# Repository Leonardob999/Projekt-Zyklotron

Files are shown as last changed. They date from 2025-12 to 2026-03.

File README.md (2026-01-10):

# Projekt-Zyklotron

Das ist unser Versuch eine eine Modell des im Cern betrienen Zyklotrons zu bauen. Unsere Nachbildung nutzt magnetische Felder um eine Magnetkugel anzutreiben. In diesem Github ist alles was ihr braucht um es zu benutzen und auch nachzubauen.

## Unser [Github](https://github.com/Leonardob999/Projekt-Zyklotron)

## Aufbau
12V an den vorgesehenen Anschlüssen anschließen. 

## Benutzung

Durch drehen des Drehknopfs kann man die Seite die auf den Display angezeigt wird auswählen. Durch drücken des Knopfes wird die Seite bestätigt und man kann jetzt den aktuellen Wert verändern. Durch erneutes betätigen des Knopfes kommt man wieder in die Seitenauswahl zurück.

## Bilder

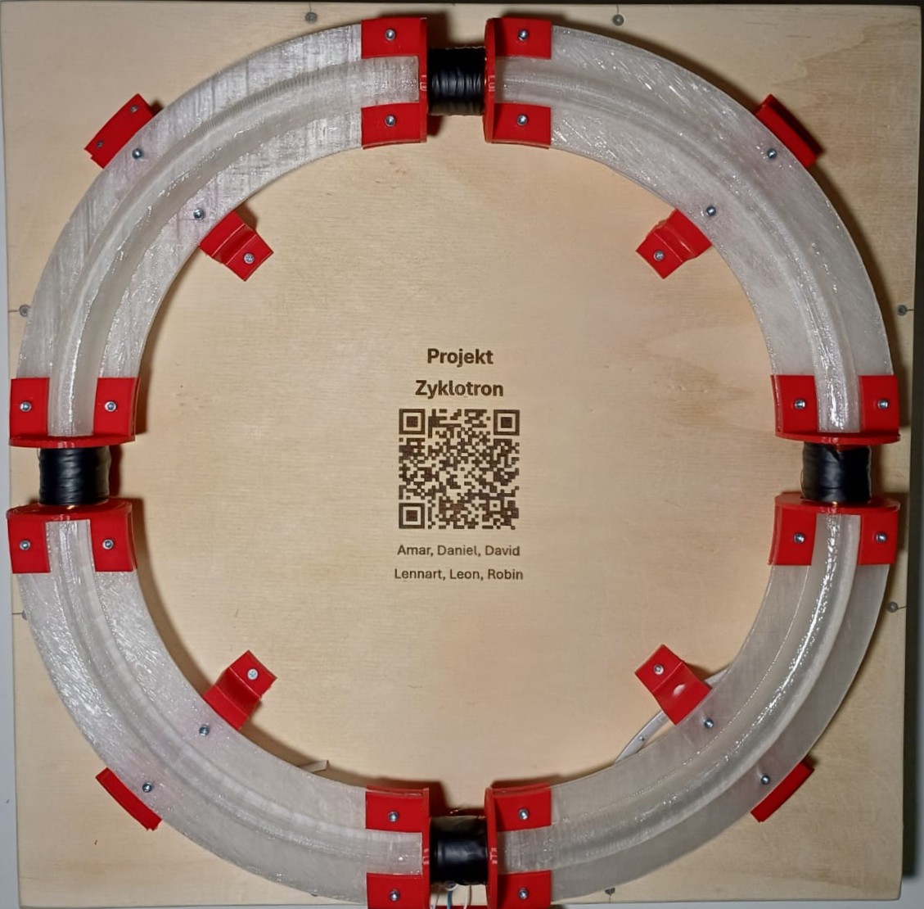
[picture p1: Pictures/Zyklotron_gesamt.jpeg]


## Autoren

- [@FritzWilli1](https://www.github.com/FritzWilli1)
- [@Fl4SH3Z](https://www.github.com/Fl4SH3Z)
- [@Danieldev1804](https://www.github.com/Danieldev1804)
- [@Leonardob999](https://www.github.com/Leonardob999)
- @Amar
- @David

## Quellen
Unsere Zyklotron Nachbildung wurde inspiriert durch ein Video von [@Marcin Poblocki](https://www.youtube.com/watch?v=sm_-i4a_vSU)

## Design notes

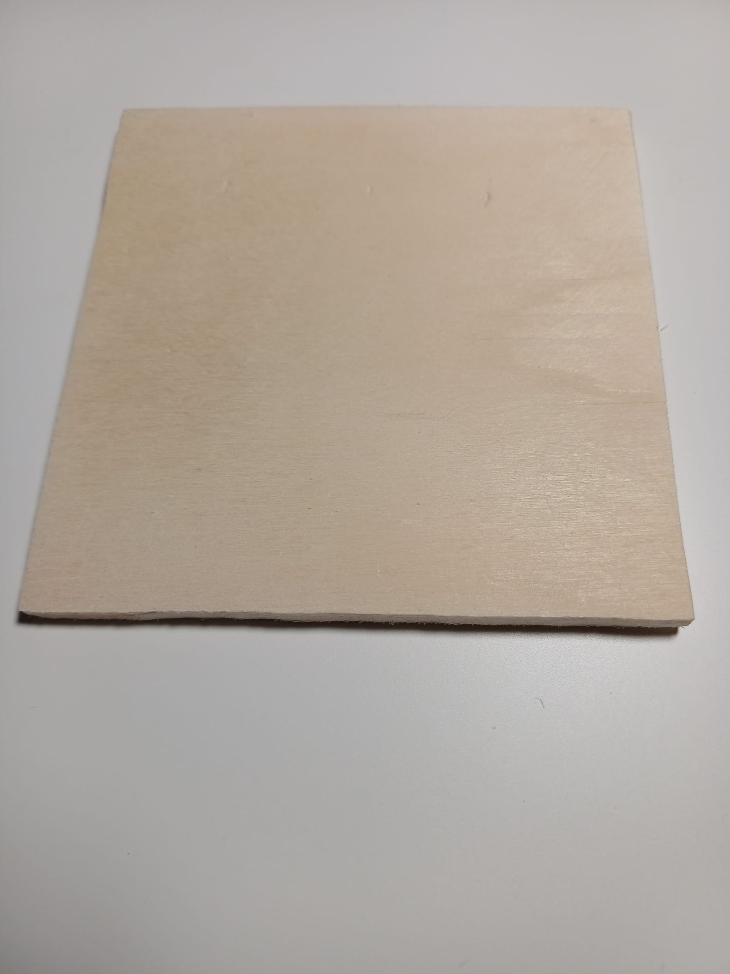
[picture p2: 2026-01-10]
Pictures/Brett.jpeg

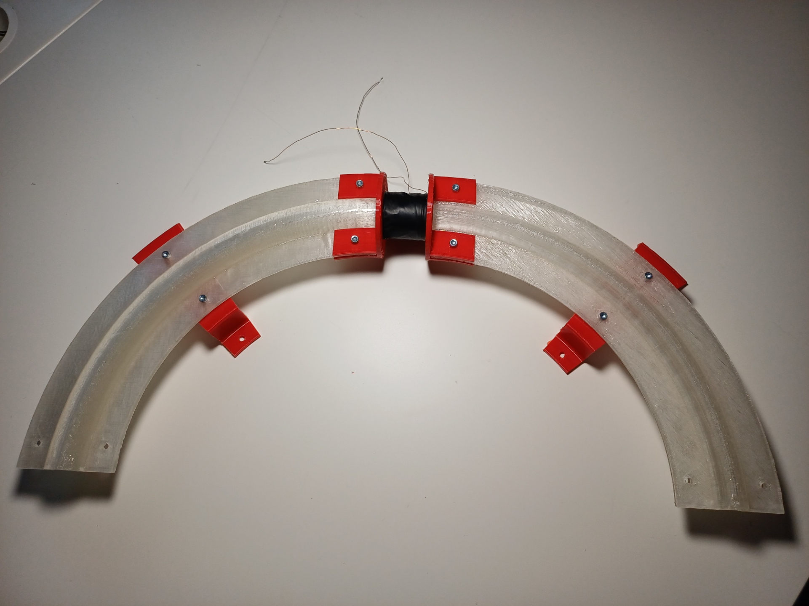
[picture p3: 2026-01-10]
Pictures/Halbr.jpg

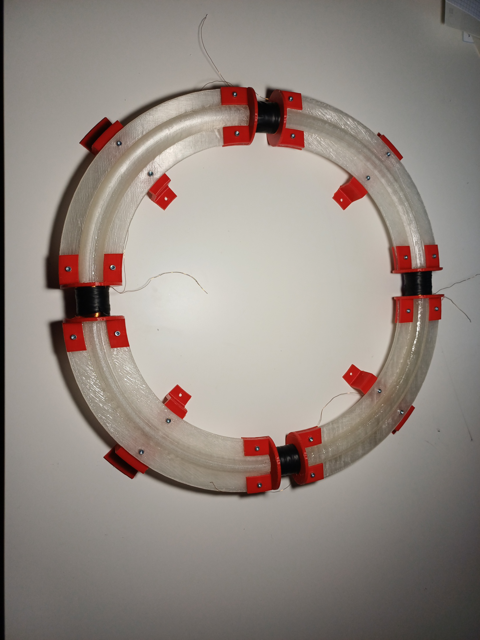
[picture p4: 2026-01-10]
Pictures/Ganzo.jpg

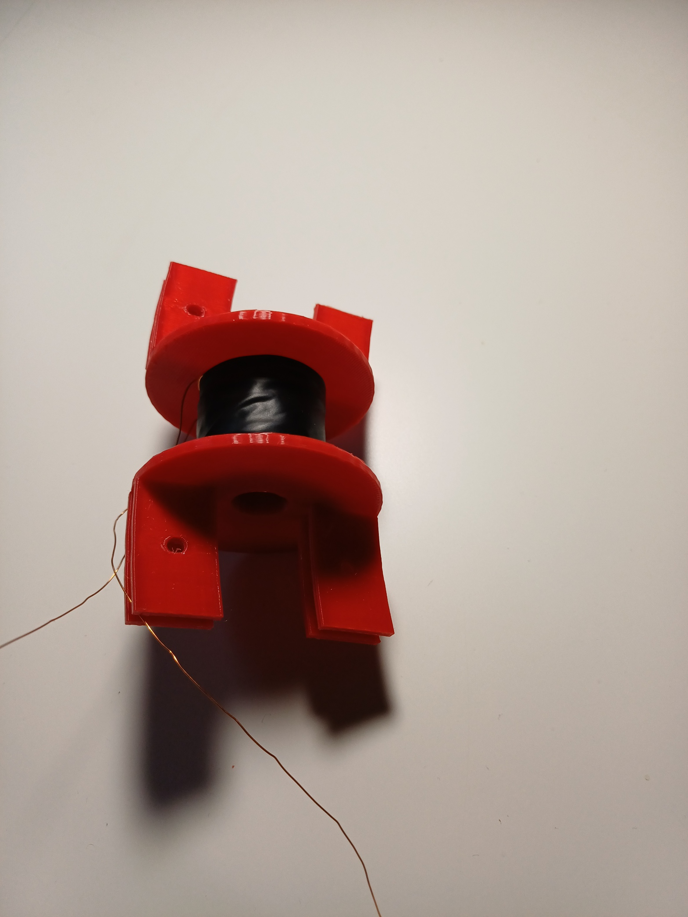
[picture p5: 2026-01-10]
Pictures/Spule.jpg

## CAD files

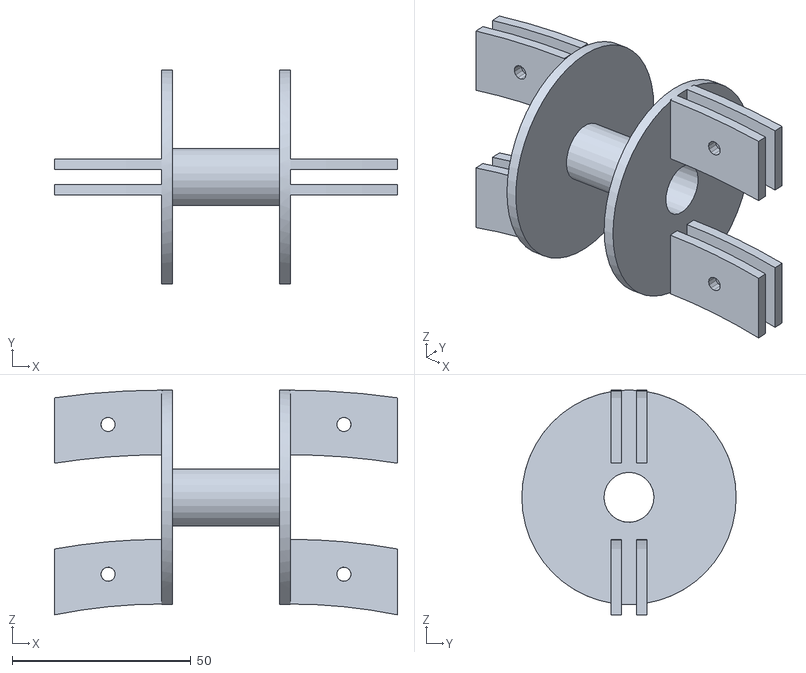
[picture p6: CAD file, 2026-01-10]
CAD/Models/stl/Verbindungsstück.stl
96.0 x 60.0 x 62.9

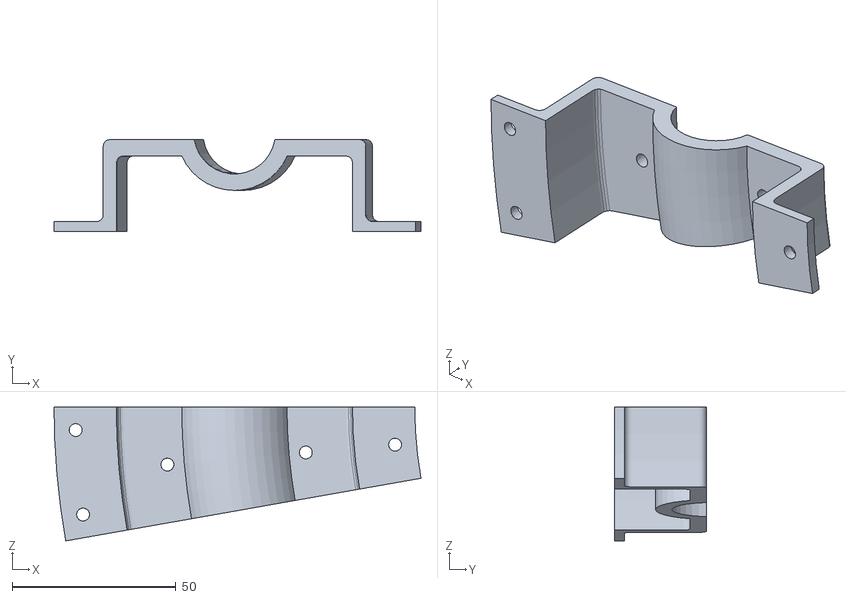
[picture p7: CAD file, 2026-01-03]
CAD/Models/stl/Stütze-Mk3.stl
111.9 x 28.0 x 40.8

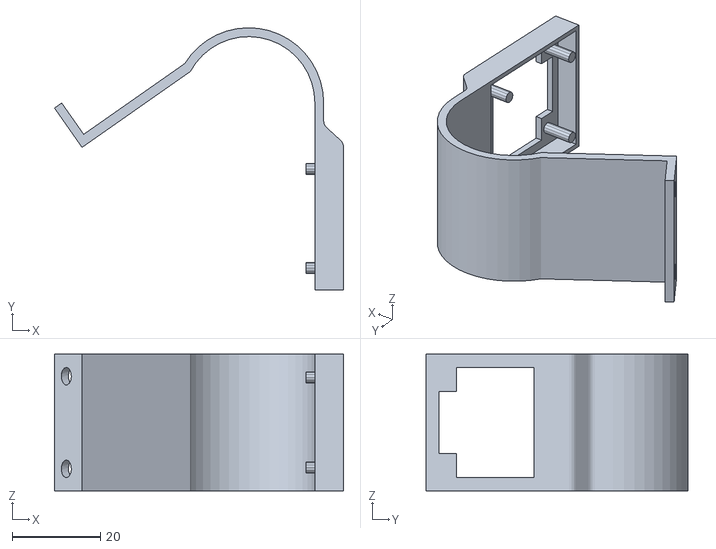
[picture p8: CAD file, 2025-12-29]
CAD/Models/stl/Bildschirmhalter-Mk5.stl
65.5 x 59.5 x 31.0

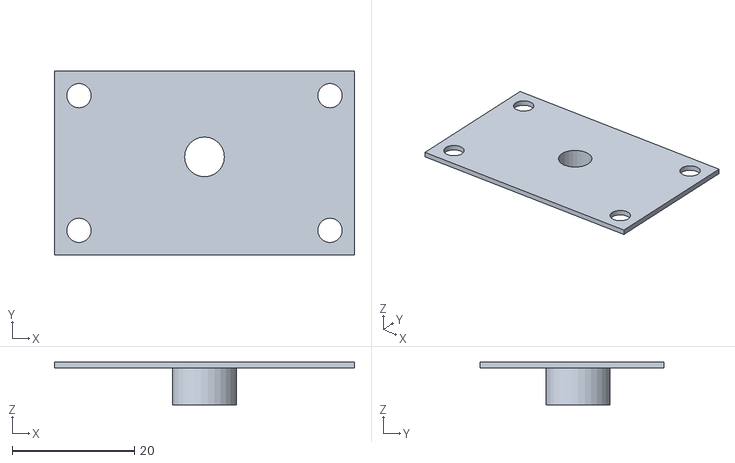
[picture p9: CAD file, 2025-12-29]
CAD/Models/stl/RE-Halter.stl
49.0 x 30.0 x 7.00

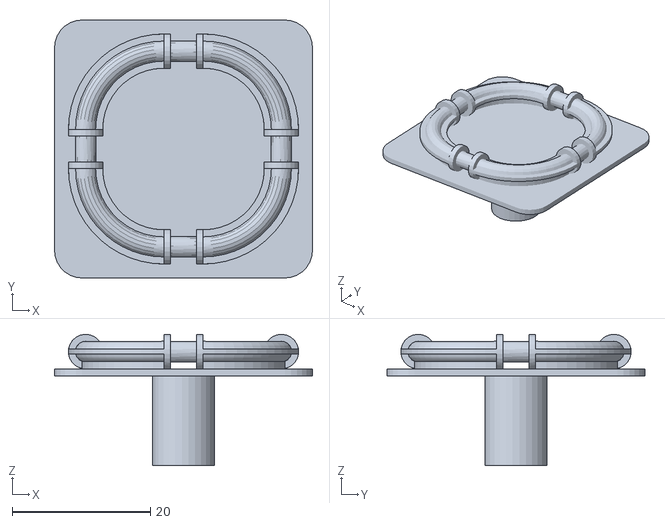
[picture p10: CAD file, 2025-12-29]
CAD/Models/stl/Knopf-Mk2.stl
37.3 x 37.3 x 19.0

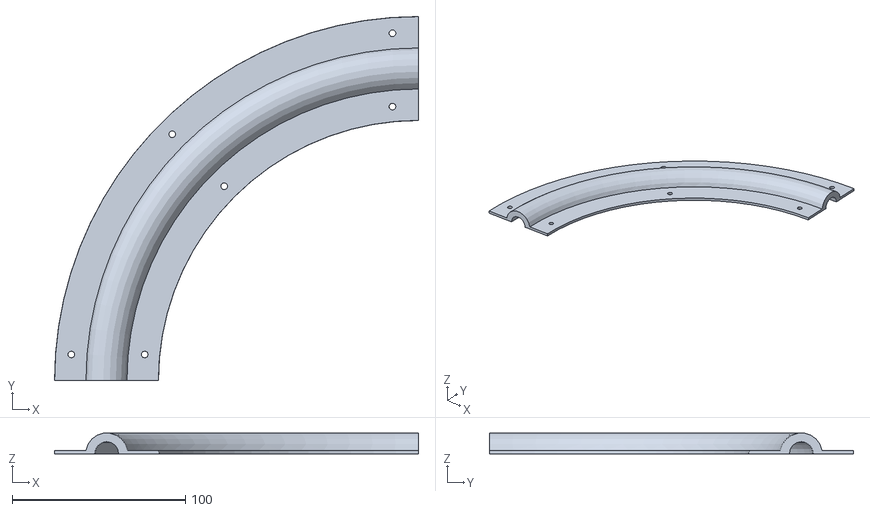
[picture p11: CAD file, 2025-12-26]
CAD/Models/stl/Kurventeil-dick.stl
210.0 x 210.0 x 11.9

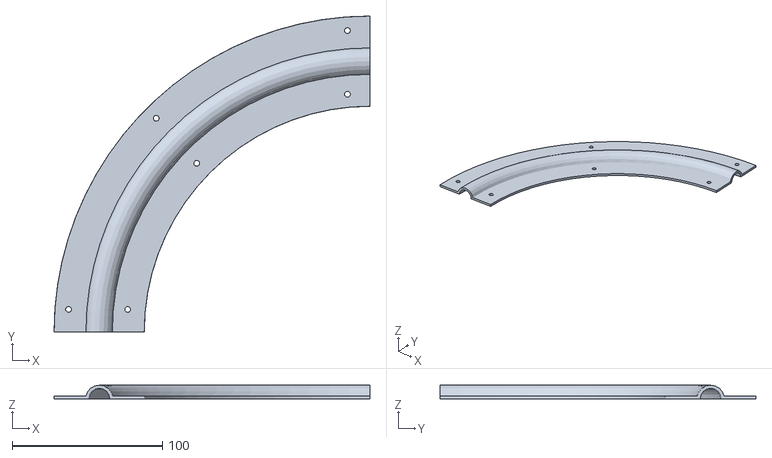
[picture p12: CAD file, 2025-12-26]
CAD/Models/stl/Kurventeil-dünn.stl
210.0 x 210.0 x 9.00

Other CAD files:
CAD/Models/ipt/Bildschirmhalter-Mk5.ipt
CAD/Models/ipt/Knopf-Mk2.ipt
CAD/Models/ipt/Kurventeil-dick.ipt
CAD/Models/ipt/Kurventeil-dünn.ipt
CAD/Models/ipt/RE-Halter.ipt
CAD/Models/ipt/Stütze-Mk3.ipt
CAD/Models/ipt/Verbindungsstück.ipt

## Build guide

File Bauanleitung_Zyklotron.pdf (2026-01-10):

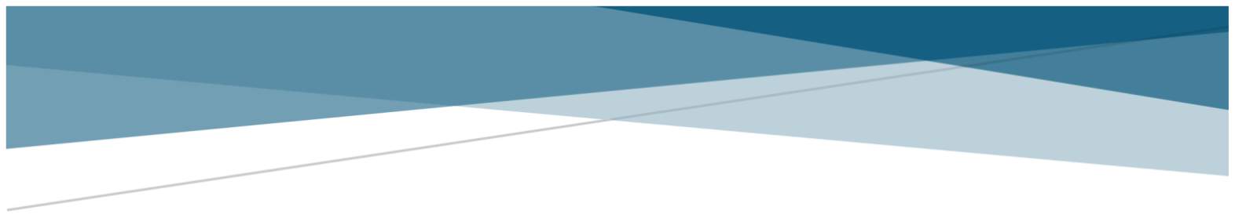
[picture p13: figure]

# ZYKLOTRON-BAUANLEITUNG

## Amar, Daniel, David, Lennart, Leon, Robin

https://leonardob999.github.io/Projekt-Zyklotron/

Amar, Daniel, David | Zyklotron
Lennart, Leon, Robin | 10. Jan. 2025

### 1 INHALT

### 2 MATERIALLISTE UND BENÖTIGTE WERKZEUGE

Mechanische Komponenten:
- 2x1KG Spulen PVB (transparent)
- PLA/PETG Spule Farbe egal
- 24x M3*16mm Zylinderkopfgewindeschrauben
- 12xM3*16mm Senkkopfgewindeschrauben
- 16xM3*25mm Senkkopfholzschrauben
- 36x M3 Muttern
- Isopropanol
- Neodymmagnetkugel
- 500mmx500mmx5mm Holzbrett
- 4x Holzlatten
Elektrische Komponenten:
- 4x 87m*0,35mm Kupferlackdraht
- Kabel
- 1xLED-Band 3-farbig (alle 15cm aufteilbar)
- Widerstände: 4x1,2kΩ; 4x4,7kΩ; 4x20kΩ; 4x10kΩ
- 2xLaborkabelbuchsen
- 1xEsp32 Microcontroller
- 1xRotary Encoder
- 1xOLed Display
- 4xHall Sensoren A3144
- 1xSpannungsregler L7805CV
- 4xFet mit Freilaufdiode
- 4xTransistor
Werkzeuge:
- Pinsel
- Dremel/Feilen
- Zange/Seitenschneider
- Lötkolben
- 3D-Drucker
- Akkuschrauber
- Stichsäge

### 3 EINFÜHRUNG

Teilchenbeschleuniger sind heutzutage wichtige Werkzeuge in Forschungsgebieten wie Materien- und Materialforschung, aber auch in der Medizin oder der Energietechnik kommen sie zum Einsatz. Da diese jedoch groß und technisch hochkomplex sind, werden solche physikalischen Abläufe vereinfacht und in Modellen dargestellt. Dies ist genau das Ziel dieses Projektes. Durch den Bau dieses Zyklotrons, als Modell eines Teilchenbeschleunigers, sind die physikalischen Zusammenhänge einfacher zu verstehen. Außerdem wird durch das Zyklotron ermöglicht theoretische Inhalte in die Praxis umzusetzen.
Dieses Projekt weicht an einigen Stellen vom realen Teilchenbeschleuniger ab, zum Beispiel basiert es nicht auf dem zusammenwirken von elektrischen und magnetischen Feldern, sondern nur auf dem Einsatz magnetischer Felder durch elektrisch gesteuerte Spulen. Daher stellt dieses Projekt nicht die genaue Wirkweise eines Teilchenbeschleunigers nach, kann aber dennoch physikalische Zusammenhänge, wie Induktion und Magnetfelder, verständlich darstellen.

### 4 VORBEREITUNG 3D-DRUCKTEILE

4.1 3D-DRUCK
Als ersten Schritt des Baus ist es nötig, die verschiedenen Modelle mit einem 3D-Drucker auszudrucken. Es werden benötigt (siehe GitHub):
- 6x Kurventeil-dick (transparentes Material)
- 2x Kurventeil-dünn (transparentes Material)
- 4x Verbindungsstück (beliebiges Material)
- 4x Stütze-Mk3 (beliebiges Material)
- 1x Bildschirmhalter-Mk5 (beliebiges Material)
- 1x Knopf-Mk2 (beliebiges Material)
- 1x RE-Halter (beliebiges Material)
Es ist auch möglich 8x Kurventeil-dünn zu verwenden. In folgender Anleitung wird jedoch 6x Kurventeil-dick verwendet, da in der vorrausgegangenen Konstruktion zuerst zu hohe Sicherheiten mit eingebaut wurden. Als dies auffiel, war der Großteil der Kurven allerdings schon gedruckt.
Die Druckeinstellungen müssen je nach Drucker und Material individuell eingestellt werden. Bei dem transparenten PVB ist es jedoch wichtig darauf zu achten, dass für eine optimale Transparenz des Filaments der Infill des Drucks auf 100% zu stellen ist, da kleine Druckfehler und Lufteinschlüsse die Transparenz deutlich beeinträchtigen. Als Füllmuster wird das geradlinige Füllmuster verwendet. Zudem sollten alle Oberflächen von den Teilen gebügelt werden, um eine saubere Oberfläche zu ermöglichen, wobei die Flussrate 20% beträgt. Schürze und Rand (Skirt und Brim) können deaktiviert werden. Stützmaterial muss generiert werden, wobei die Form irrelevant ist. Für weitere Details kann das Druckprofil via GitHub heruntergeladen werden. Dieses ist im CAD-Ordner als config.ini zu finden, muss allerdings noch auf den verwendeten Drucker angepasst werden.
Die Stützen, die Verbindungsstücke, die Displayhalterung und die Teile für den Rotary Encoder können aus einem beliebigen stabilen und plastischen Stoff gedruckt werden, da hier die Transparenz keine Rolle spielt. Hierbei werden die Teile mit der jeweiligen Standardeinstellung des Materials gedruckt.

### 4.2 NACHBEARBEITUNG

Nachdem die Teile vom 3D-Drucker fertiggestellt wurden, wird der Großteil des Supports mithilfe von Zangen und Seitenschneidern entfernt. Danach müssen die feineren, noch übrig gebliebenen, Strukturen des Supports mithilfe eines Dremels oder einer Feile entfernt werden (Schritt 1). Besonders zu beachten ist hier, dass an Verbindungsrelevanten Stellen nicht zu viel Material abgetragen werden darf, damit die Schraubverbindungen einwandfrei funktionieren.
Nachdem der Support so gut wie möglich entfernt wurde, sollten die Kurventeile noch mit Isopropanol behandelt werden, um die Transparenz und die Materialoberfläche zu verbessern. Hierfür wird ein Pinsel in das Isopropanol getunkt und dieses vorsichtig auf den Druck aufgetragen. Dieser Vorgang wird mehrfach wiederholt, bis die Oberfläche möglichst glatt und widerstandslos für die Kugel ist und das Kurventeil möglichst durchsichtig.

### 5 ZUSAMMENBAU 3D-DRUCK

Nachdem alle 3D-Druckteile fertig nachbearbeitet wurden, müssen die Spulen auf die Verbindungsstücke gewickelt werden (Schritt 2). Hierfür kann ein Akkuschrauber verwendet werden. Jede Spule wird einzeln mit 87m Draht gewickelt. Es muss darauf geachtet werden, dass an beiden Enden noch genug freier Draht ist, um die Spule an die Schaltung anschließen zu können. Es sollte außerdem darauf geachtet werden, dass die Spulen möglichst genau gewickelt werden, da eine unsauber gewickelte Spule das Magnetfeld negativ beeinflusst. Wenn die Spule gewickelt wurde wird sie mit Isoband umwickelt um den Draht zu fixieren.
Für den Zusammenbau werden M3 Schrauben und Muttern verwendet.
Hilfreich ist es, wenn zuerst zwei Kurventeile übereinandergelegt und mit einer Stütze an den mittleren Löchern verbunden werden (Schritt 3). Dies wird für alle vier Viertel gemacht, wobei die zwei Kurventeile-dünn optimalerweise auf der Oberseite und diagonal gegenüber platziert werden sollten. Daraufhin müssen die Viertel nun mit den Verbindungsstücken verbunden werden, indem diese auf die vier Viertel geschoben und daraufhin mit Schrauben verbunden werden. (Schritt 4 + 5)

### 6 BASIS

### 6.1 BRETT

Wenn das Zyklotron zusammengesetzt wurde kann dieses nun mittig auf das Brett gesetzt werden. Danach werden mithilfe eines Bleistiftes die Löcher in den Stützen markiert. Außerdem werden die Löcher für die Kabel markiert. Diese müssen pro Verbindungsstück zentral unter der Spule sitzen sowie rechts und links von der Spule mit einem Abstand von ca. 32mm zum zentralen Loch. Die markierten Löcher können nun gebohrt werden (Schritt 6). Zudem wird der Platz in der Mitte ausgemessen, um die Gravur zu zentrieren. Danach wird jetzt die Beschriftung in der Mitte des Brettes eingraviert (Schritt 7). Nachdem die Gravur fertiggestellt wurde, sollte das Brett möglichst mit Druckluft abgeblasen werden, um es von liegengebliebenen Spänen zu befreien. Danach kann das Brett noch eingewachst werden, um es vor Verschmutzung oder Beschädigungen zu schützen (WICHTIG: Das Wachs erst nach der Gravur auftragen! Akute Brandgefahr!).

### 6.2 RAHMEN

Bevor mit dem Bau des Rahmens begonnen werden kann, muss zuerst die Frontlatte bearbeitet werden, das heißt in die Frontlatte muss eine Aussparung für den Rotary Encoder gesägt werden (Schritt 8). Danach wird der Rahmen, der dem Brett Stabilität verleiht und die Schaltung versteckt aus 4 Latten und 8 Holzschrauben zusammengebaut. Dabei muss darauf geachtet werden, dass dieser mit dem Brett abschließend gebaut wird. Außerdem müssen an beliebiger Stelle noch zwei passende Langlöcher für den Stromanschluss gebohrt werden. Dieser wird mithilfe zweier Laborkabelbuchsen realisiert. Die Verbindung mit dem Brett wird mit 2 Schrauben pro Latte realisiert (Schritt 9). Nun wird das Zyklotron mit den vorbereiteten Löchern auf dem Brett verschraubt (Schritt 10).

### 7 SCHALTUNG

Im Folgenden muss nun noch die Schaltung, nach gezeigtem Schaltplan gelötet werden. Die Schaltung wird mithilfe einer Platine geordnet und unter das Brett geklebt. Die beiden oberen Anschlüsse GND und +12V werden mit den Laborkabelbuchsen verlötet. Beim Löten der Schaltung muss darauf geachtet werden, dass die Kabel für die Spulen, die LED-Streifen, den Rotary Encoder, und den Bildschirm lang genug sind, um durch die jeweiligen Löcher zu reichen. Außerdem muss auf die richtige Anschlussweise der verschiedenen Bauteile geachtet werden, da ansonsten die Wirkweise verändert wird, oder Teile der Schaltung beschädigt werden können.

Die Spulen werden mithilfe der zentralen Löcher unter jeder Spule an die Schaltung angeschlossen. Außerdem werden die LED-Bänder an die Innenseiten der Kurventeile befestigt, um das Zyklotron von unten zu beleuchten und damit die Kugel besser sichtbar zu machen. Hierfür werden die Löcher links und rechts der jeweiligen Spule als Kabeldurchführung verwendet. Die vier Operationsverstärker am unteren Ende stellen die vier Hall-Sensoren dar. Das Bauteil OLED ist der Bildschirm und wird mithilfe des Bildschirmhalters an der vorderen Spule befestigt. Das Bauteil RE ist der Rotary Encoder und wird nach dem Löten mit der Halterung in die Aussparung des Rahmens eingesetzt. Später wird der Bildschirm mithilfe des Rotary Encoders angesteuert, indem durch Rotation zwischen Menüs umgeschaltet wird und durch drücken ein Menü aus- oder abgewählt wird. Das drehen innerhalb eines Menüs führt zur Änderung des ausgewählten Parameters.

### 8 PROGRAMMCODE

Abschließend muss der ESP32 Microcontroller noch programmiert werden. Der dafür verwendete Code kann über GitHub heruntergeladen werden. Dieser ist unter Code/zyklotron-main zu finden. Dann wird der Ordner in der Arduino IDE geöffnet und das main.ino File auf den ESP32 geflasht. Hierbei muss insbesondere darauf geachtet werden, dass die Pins die in der Schaltung verlötet wurden mit denen im Programmcode übereinstimmen.

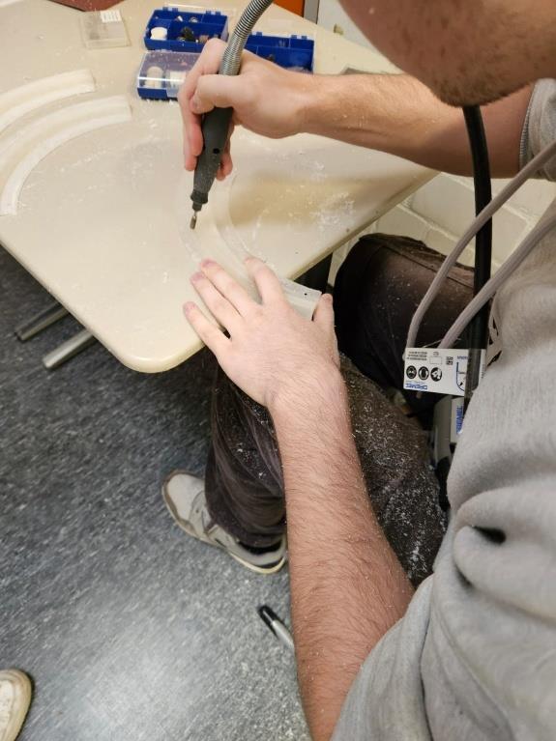
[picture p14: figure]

Abbildung 1: Nachbearbeitung

### 9 BILDANLEITUNG

SCHRITT 1:

Abbildung 5: Spule

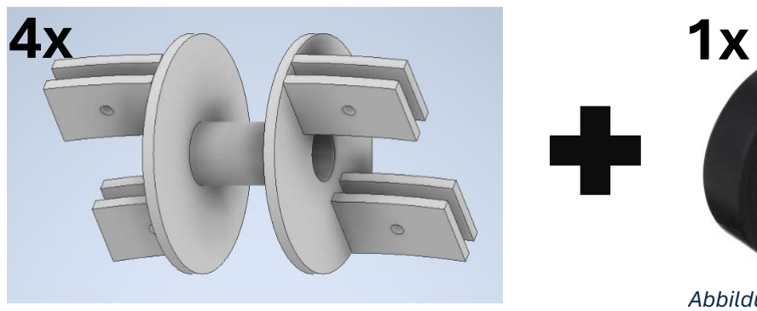
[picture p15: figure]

Abbildung 5: Verbindungsstück Modell

Abbildung 5: Isoband

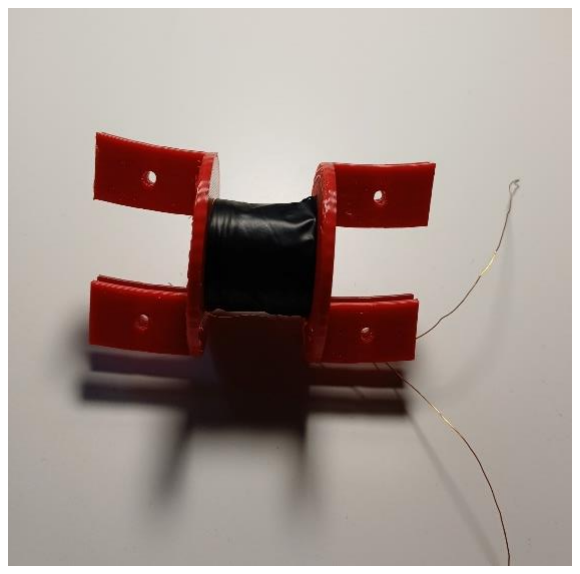
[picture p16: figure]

Abbildung 5: Verbindungsstück mit Spule

SCHRITT 2:

4x

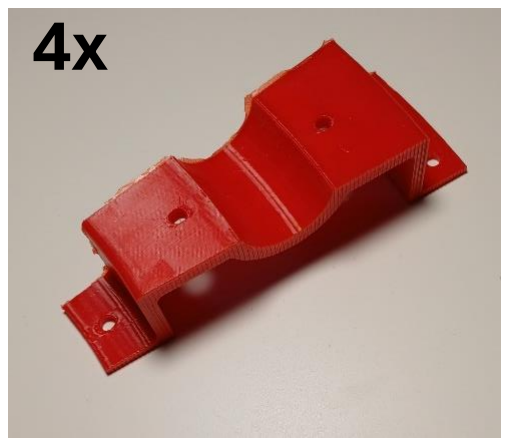
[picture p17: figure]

Abbildung 6: Stütze

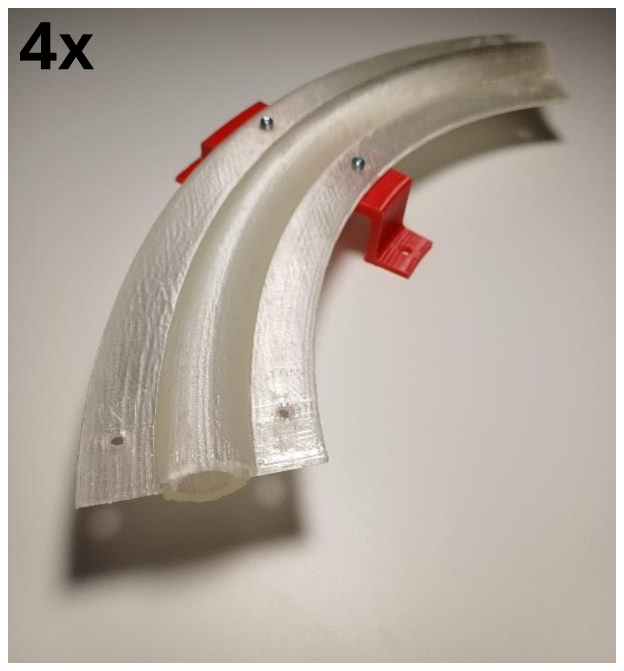
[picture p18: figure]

Abbildung 9: Viertel montiert

SCHRITT 3:

8x

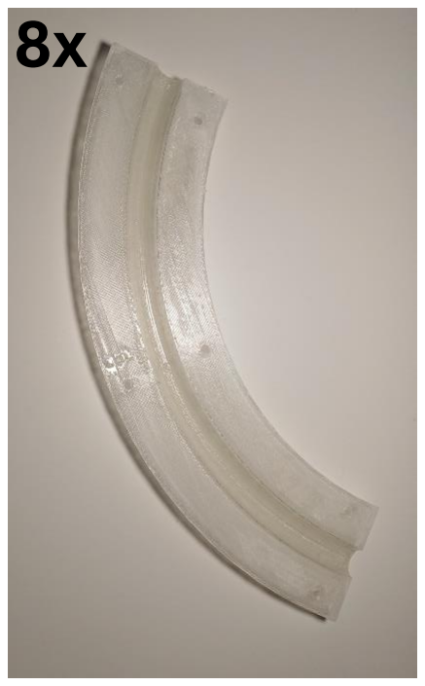
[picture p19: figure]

Abbildung 7: Kurventeil

Abbildung 8:
Schraube M3 x 16
und Mutter M3

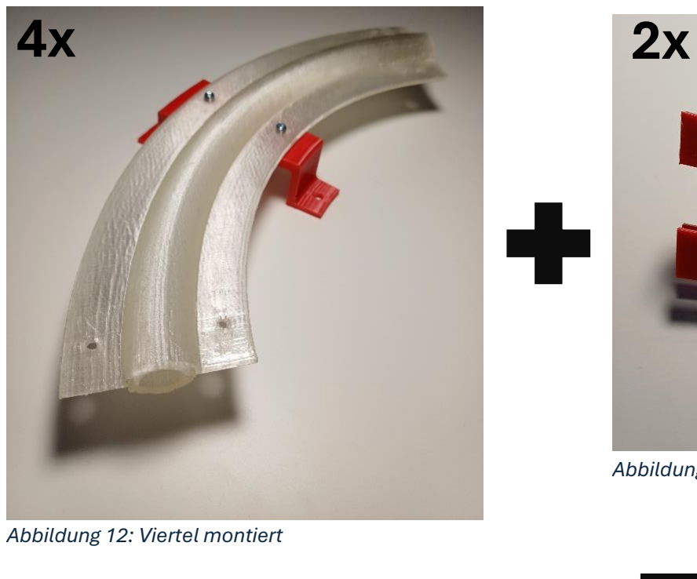
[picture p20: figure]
Abbildung 12: Viertel montiert
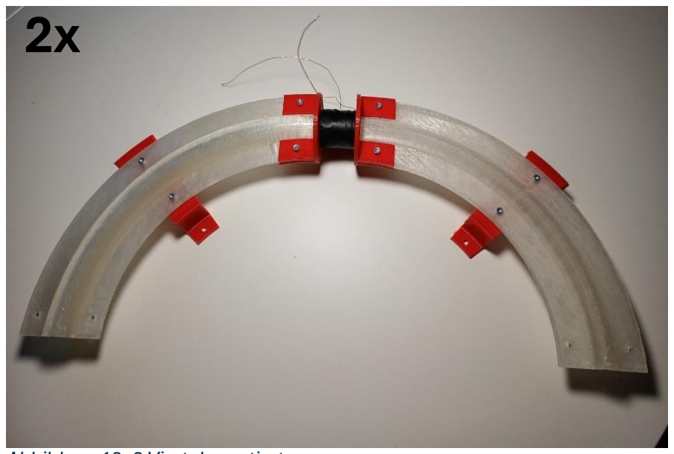
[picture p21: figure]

Abbildung 13: 2 Viertel montiert

Abbildung 12: Verbindungsstück mit Spule

SCHRITT 4:

Abbildung 15: 2 Viertel montiert

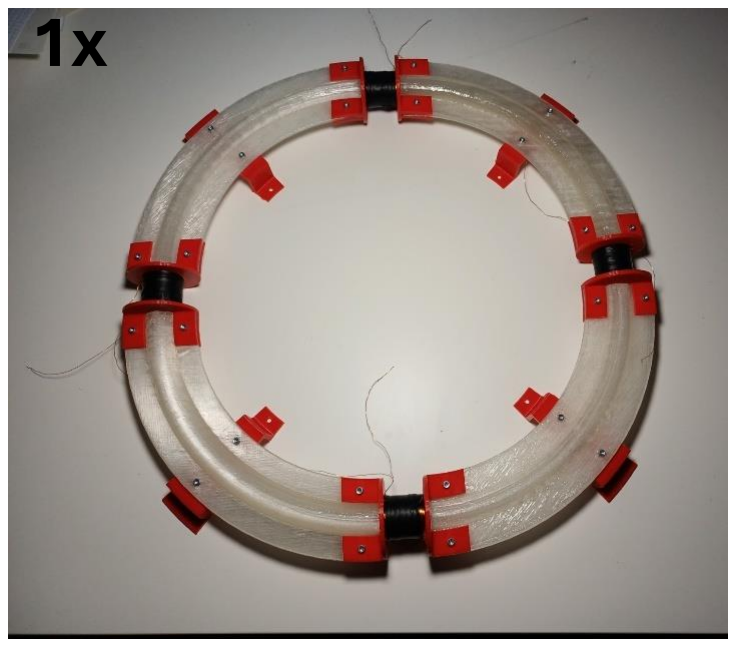
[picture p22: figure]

Abbildung 17: 4 Viertel montiert

SCHRITT 5:

Abbildung 16: Verbindungsstück mit Spule

Abbildung 14:
Schraube M3 x 16
und Mutter M3

8x

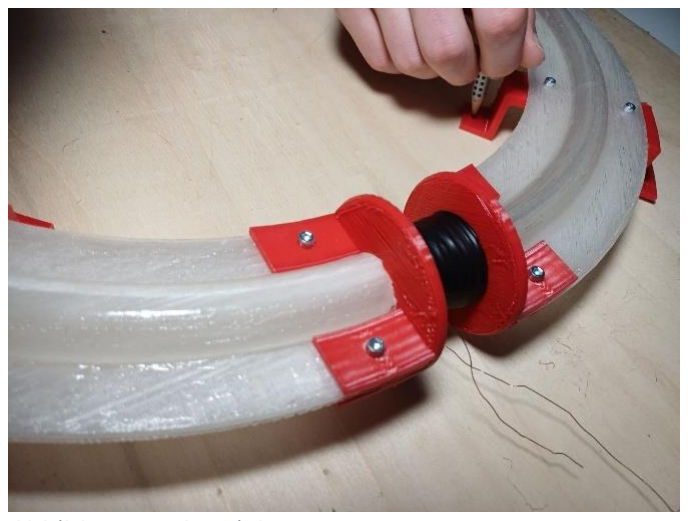
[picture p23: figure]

Abbildung 21: Anzeichnen

Abbildung 22: Bohren

SCHRITT 6:

Abbildung 20: 4 Viertel montiert

Abbildung 19: Brett 500x500 | Abbildung 18: Akkubohrmaschine

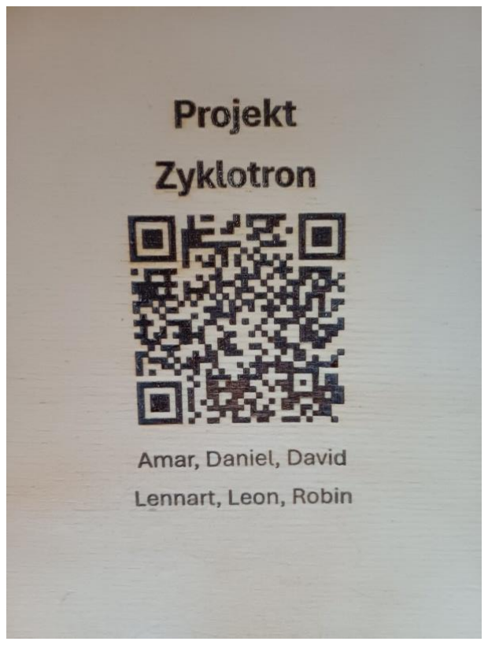
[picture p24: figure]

Abbildung 25: Gravur

SCHRITT 7:

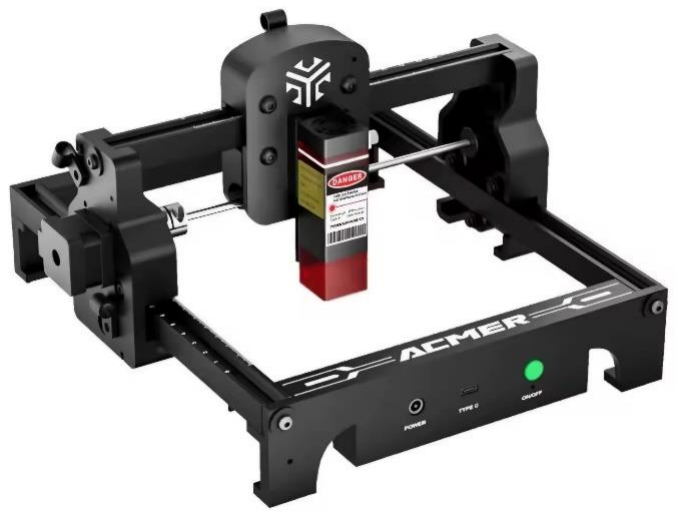
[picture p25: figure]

Abbildung 24: Brett 500x500 | Abbildung 23: Gravierer

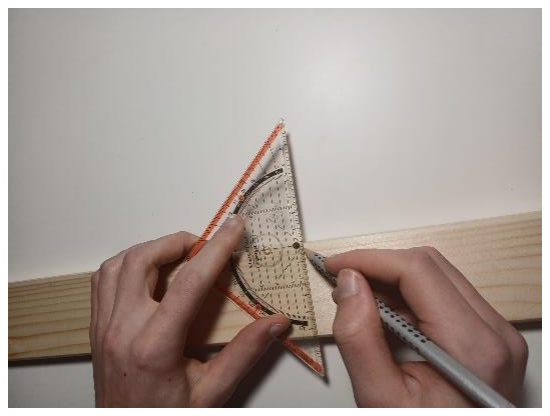
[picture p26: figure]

Abbildung 28: Latte Anzeichnen

Abbildung 29: Latte sägen

SCHRITT 8:

Abbildung 26: Latte

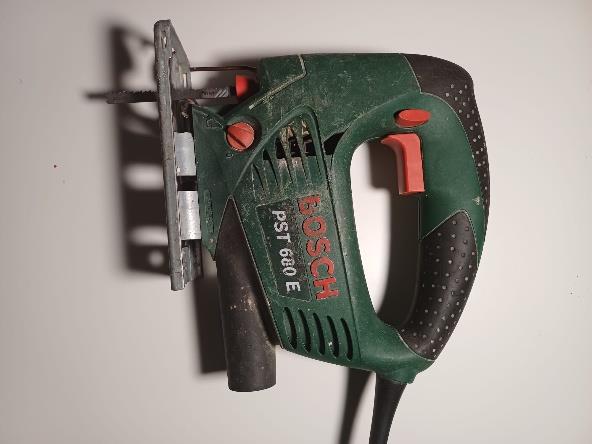
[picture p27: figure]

Abbildung 27: Stichsäge

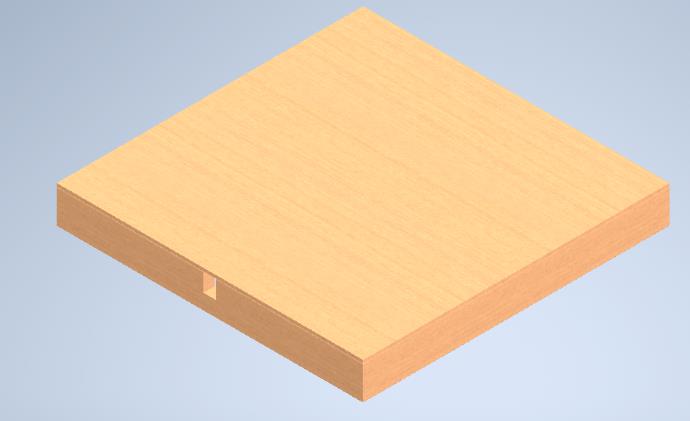
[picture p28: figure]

Abbildung 33: Brett auf Rahmen montiert

Abbildung 31: M3 x
25mm
Senkkopfschraube

SCHRITT 9:

Abbildung 30: Rahmenmodell Abbildung 32: Brett 500x500

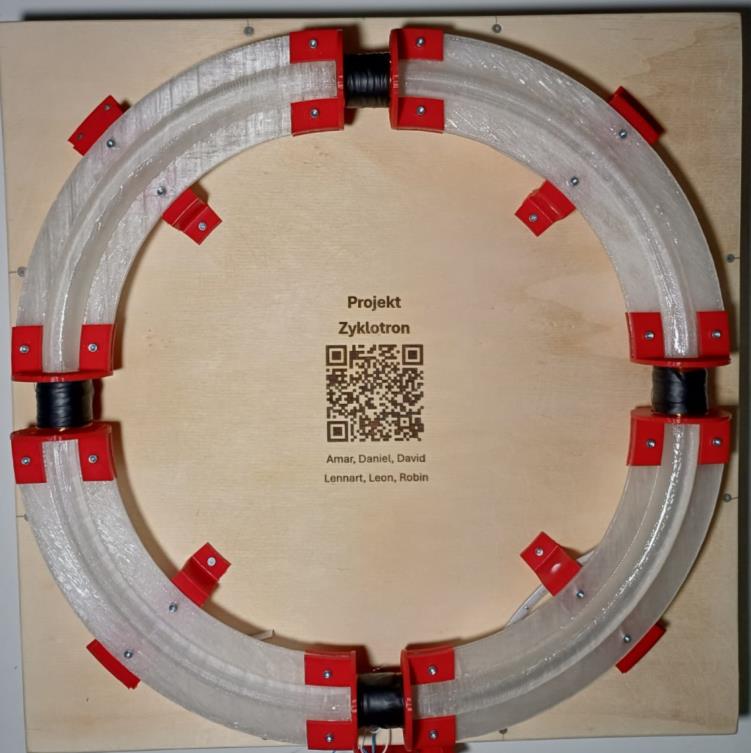
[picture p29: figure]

Abbildung 36: Zyklotron auf Basis montiert

SCHRITT 10:

Abbildung 34: Basis gesamt | Abbildung 35: 4 Viertel montiert

18

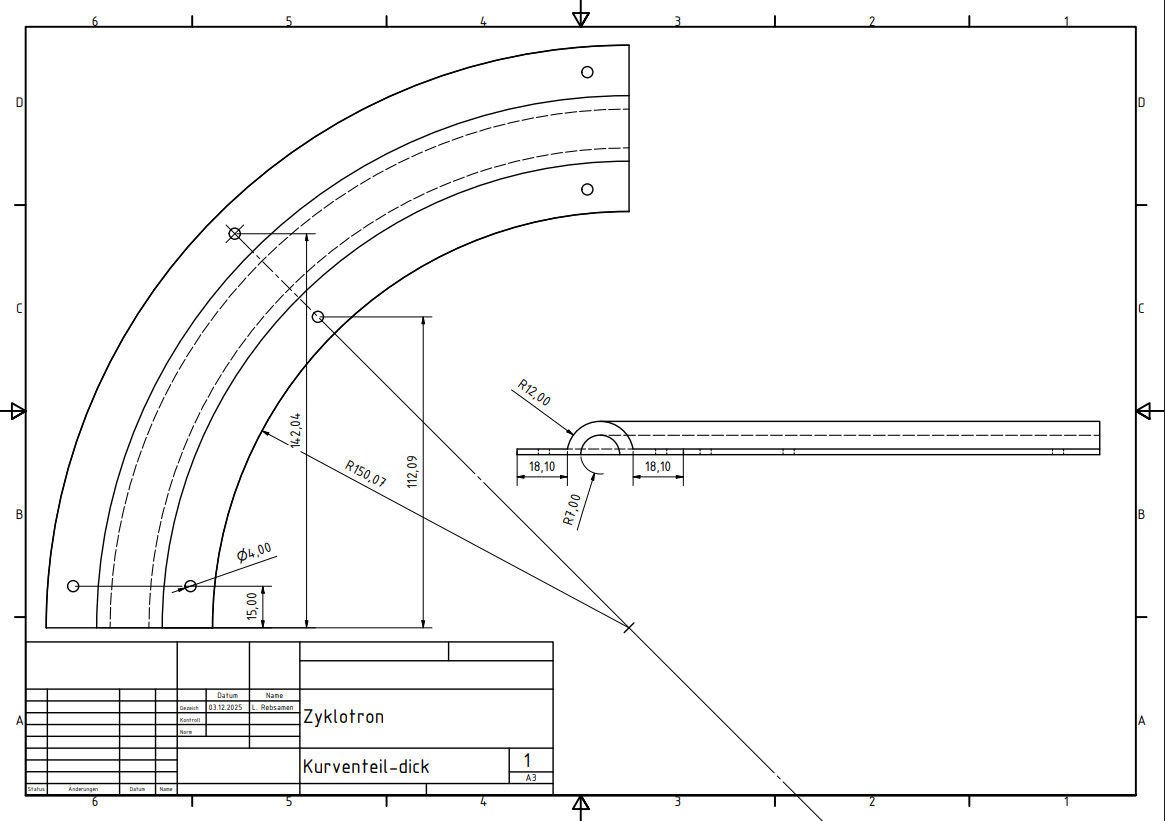
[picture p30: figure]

Abbildung 37: Technische Zeichnung Kurventeil-dick

### 10TECHNISCHE ZEICHNUNGEN

Lennart, Leon, Robin | 10. Jan. 2025

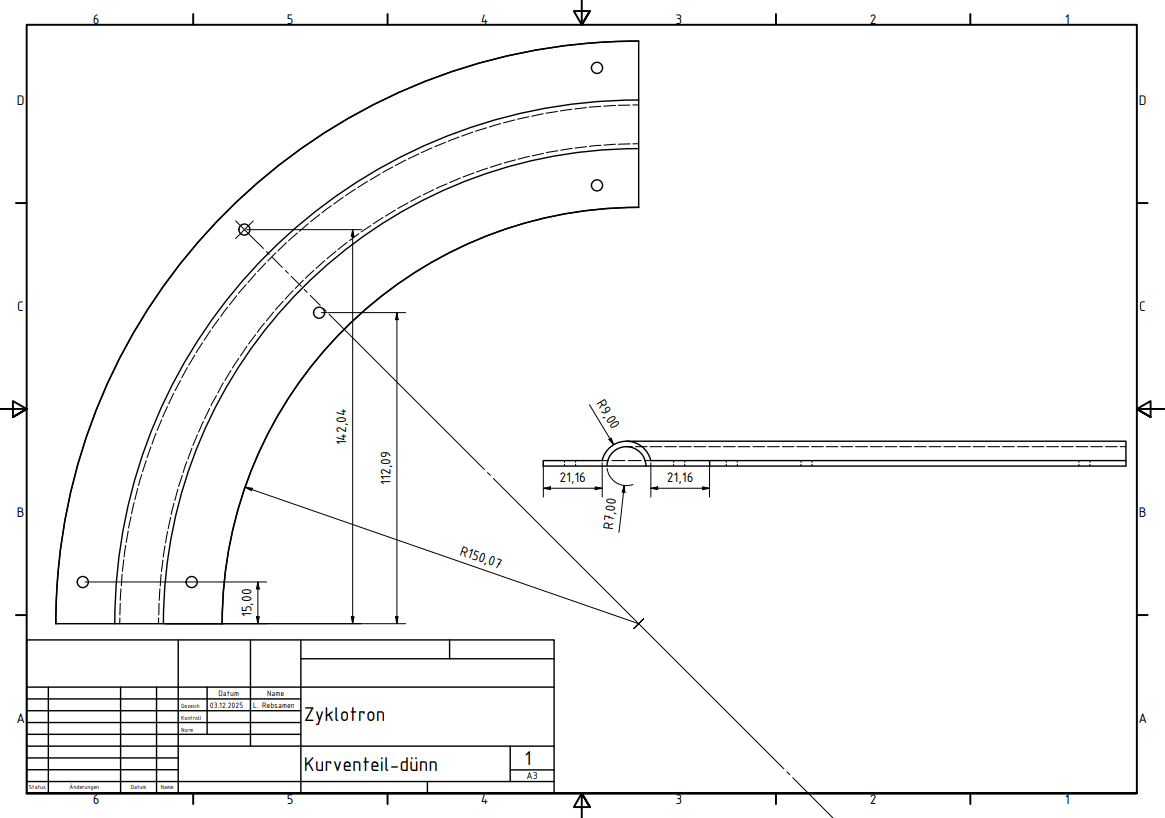
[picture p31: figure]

19 Abbildung 38: Technische Zeichnung Kurventeil-dünn

Lennart, Leon, Robin | 10. Jan. 2025

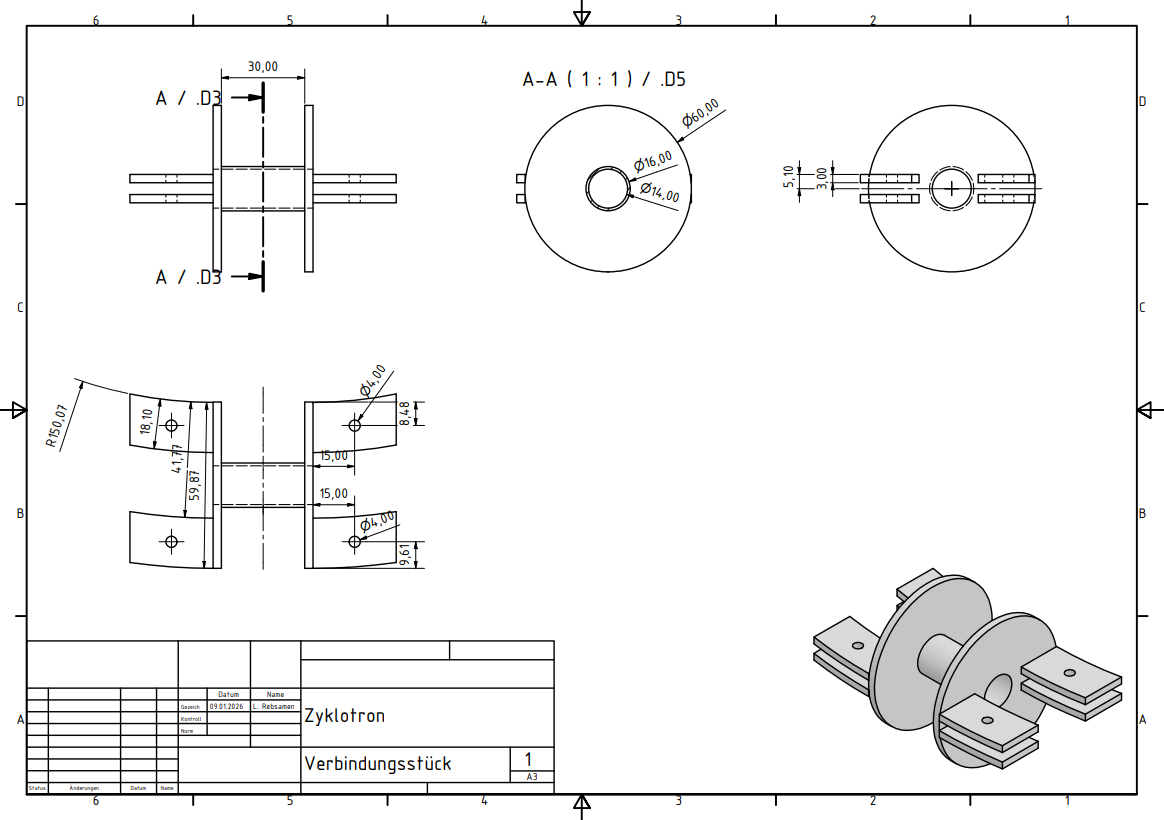
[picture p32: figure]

20 Abbildung 39: Technische Zeichnung Verbindungsstück

Lennart, Leon, Robin | 10. Jan. 2025

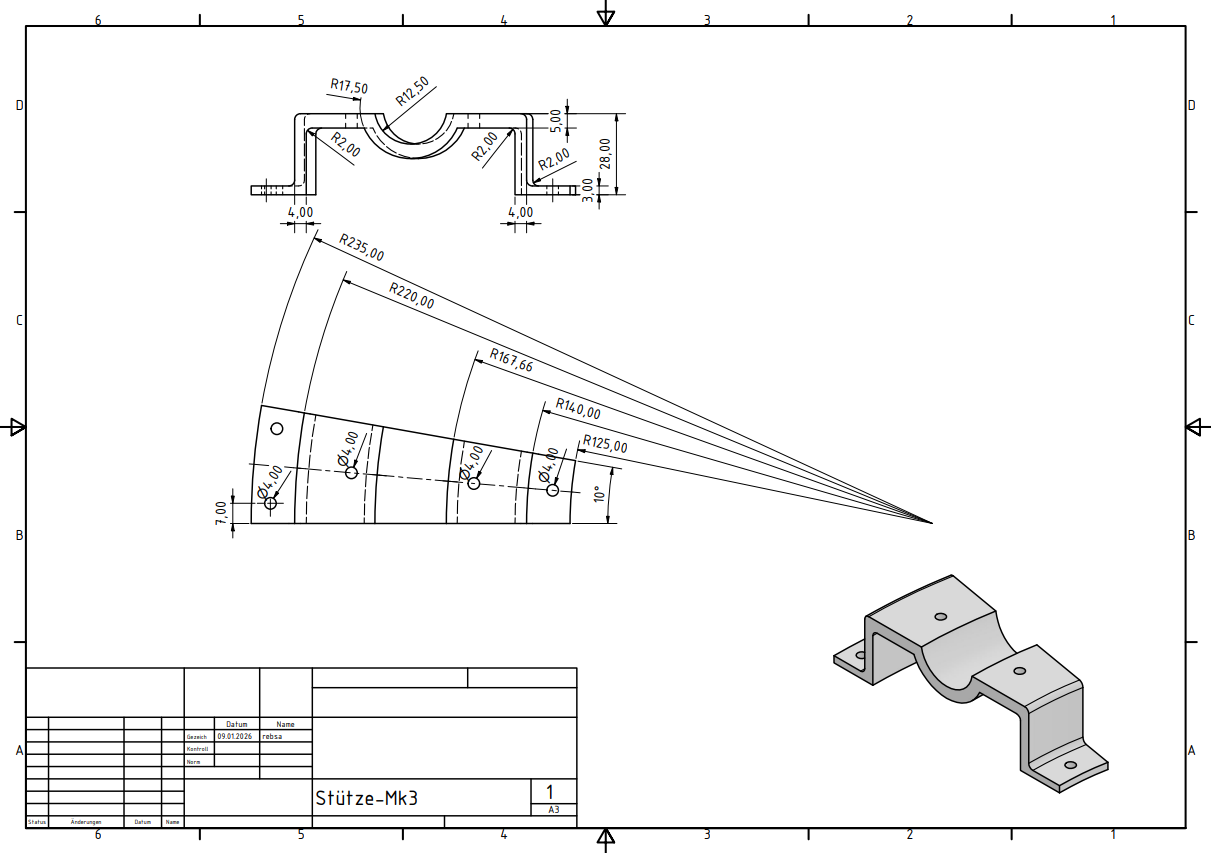
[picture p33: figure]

21 Abbildung 40: Technische Zeichnung Stütze-Mk3

Lennart, Leon, Robin | 10. Jan. 2025

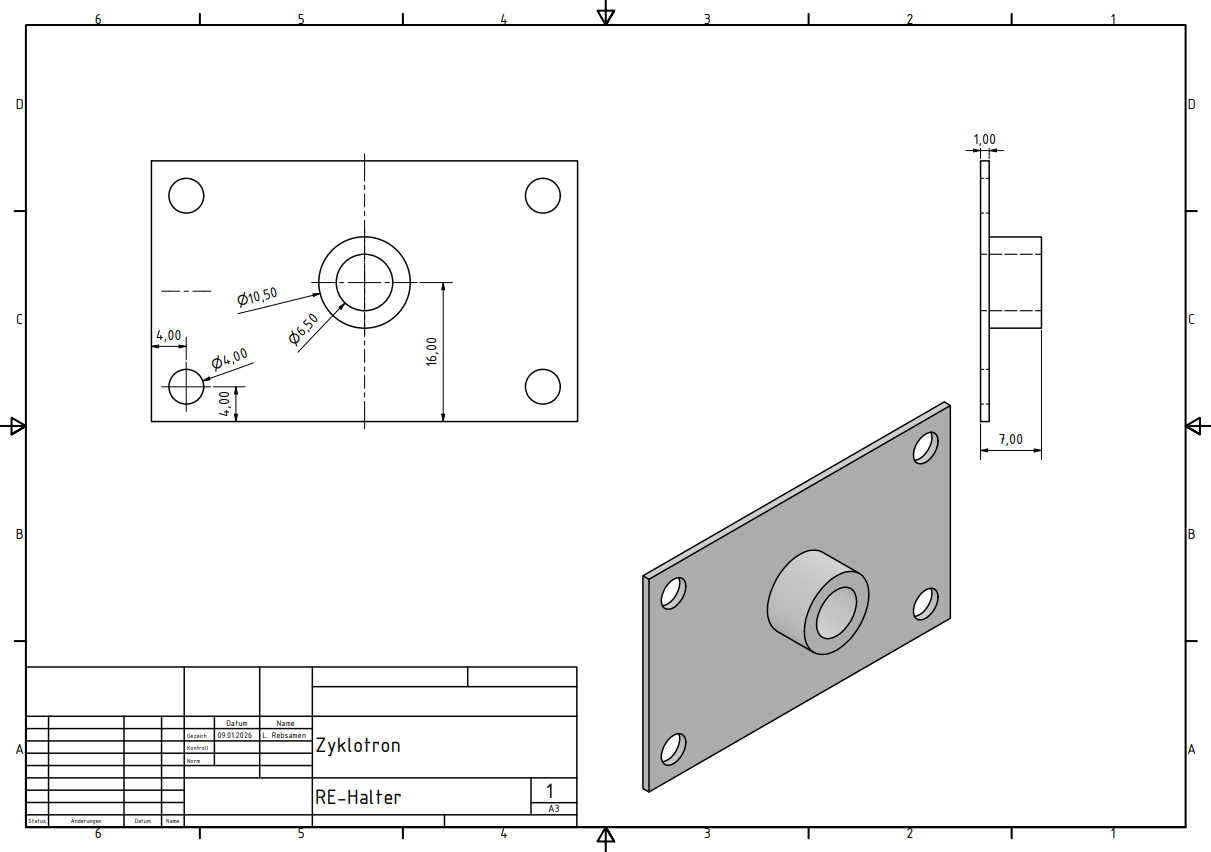
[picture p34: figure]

22 Abbildung 41: Technische Zeichnung RE-Halter

Lennart, Leon, Robin | 10. Jan. 2025

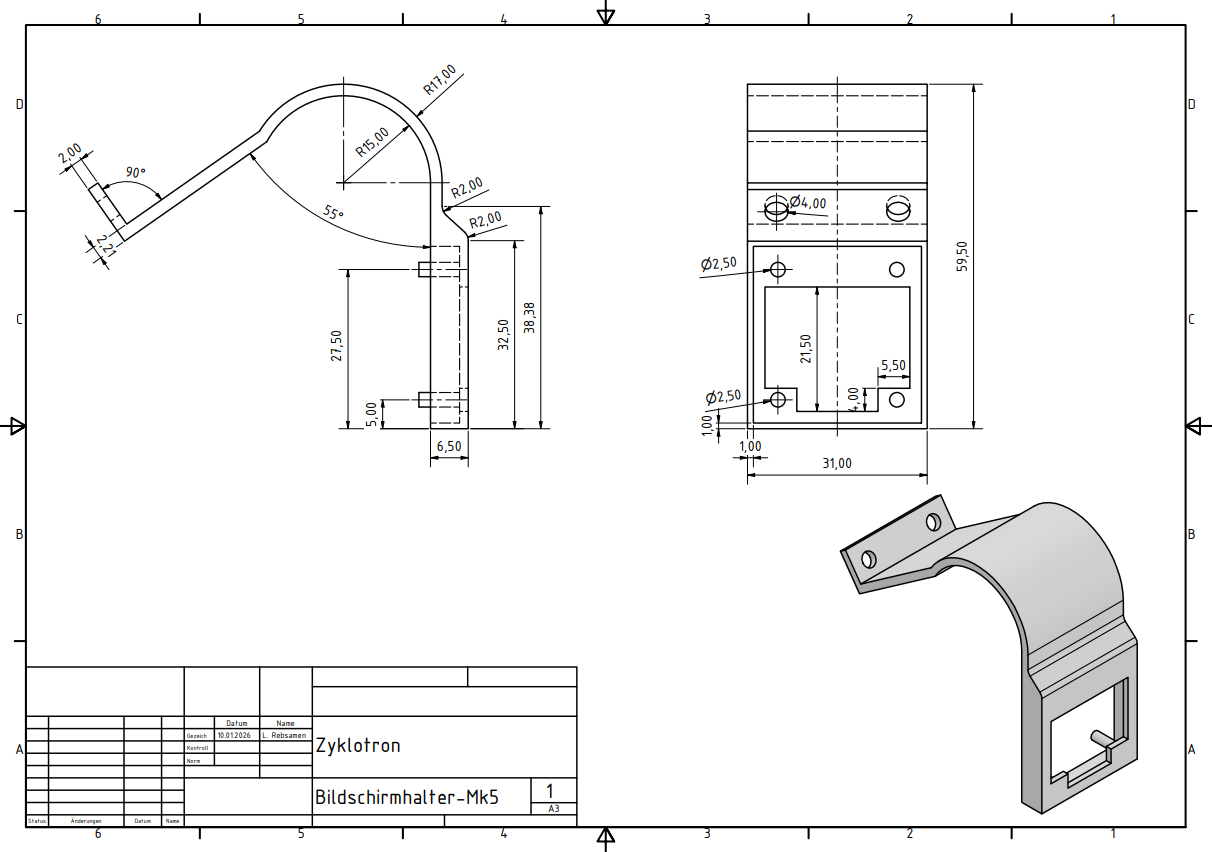
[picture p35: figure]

23 Abbildung 42: Technische Zeichnung Bildschirmhalter-Mk5

Lennart, Leon, Robin | 10. Jan. 2025

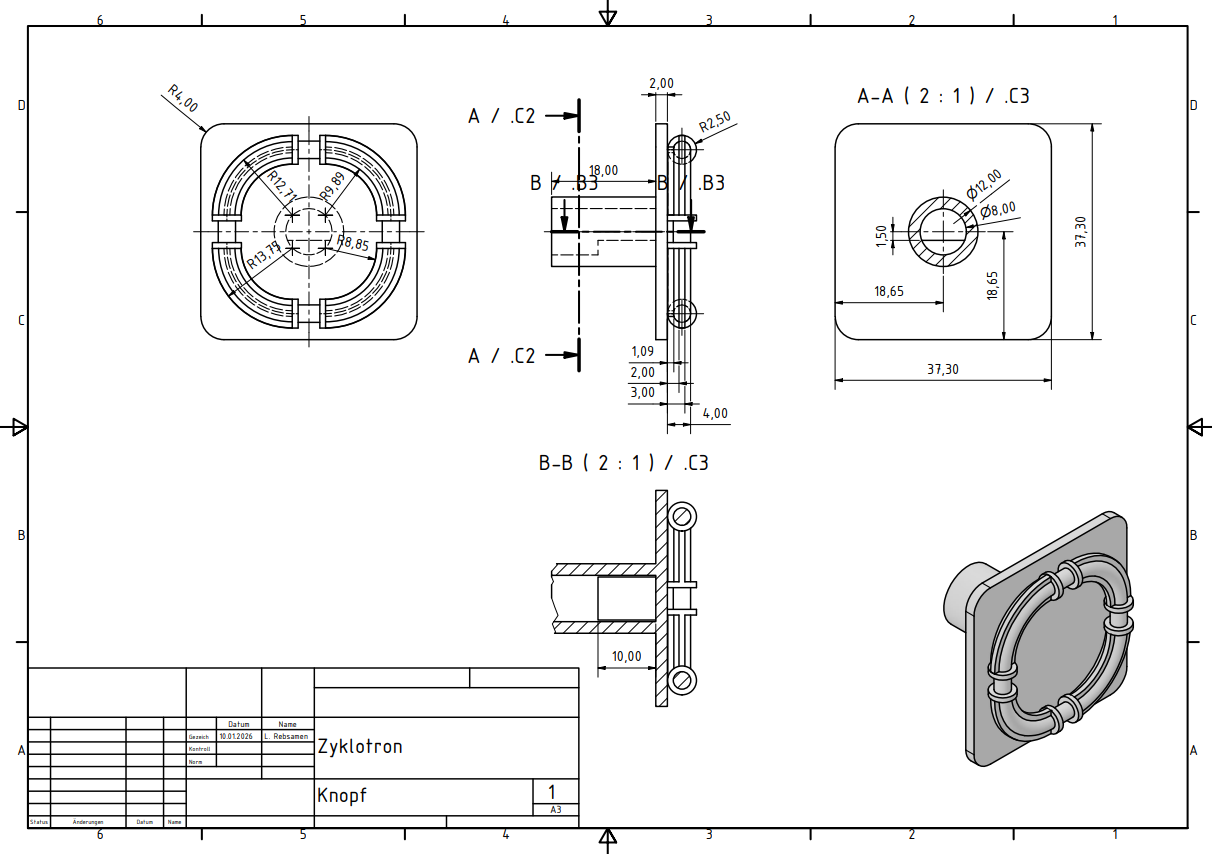
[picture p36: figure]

24 Abbildung 43: Technische Zeichnung Knopf

### 11QUELLEN

Die grundsätzliche Idee für dieses Projekt stammt von folgendem Video: https://www.youtube.com/watch?v=sm_-i4a_vSU.
Planung, Konstruktion und Bau wurde jedoch unabhängig von dieser Quelle ausgeführt.

### 12ABBILDUNGSVERZEICHNIS

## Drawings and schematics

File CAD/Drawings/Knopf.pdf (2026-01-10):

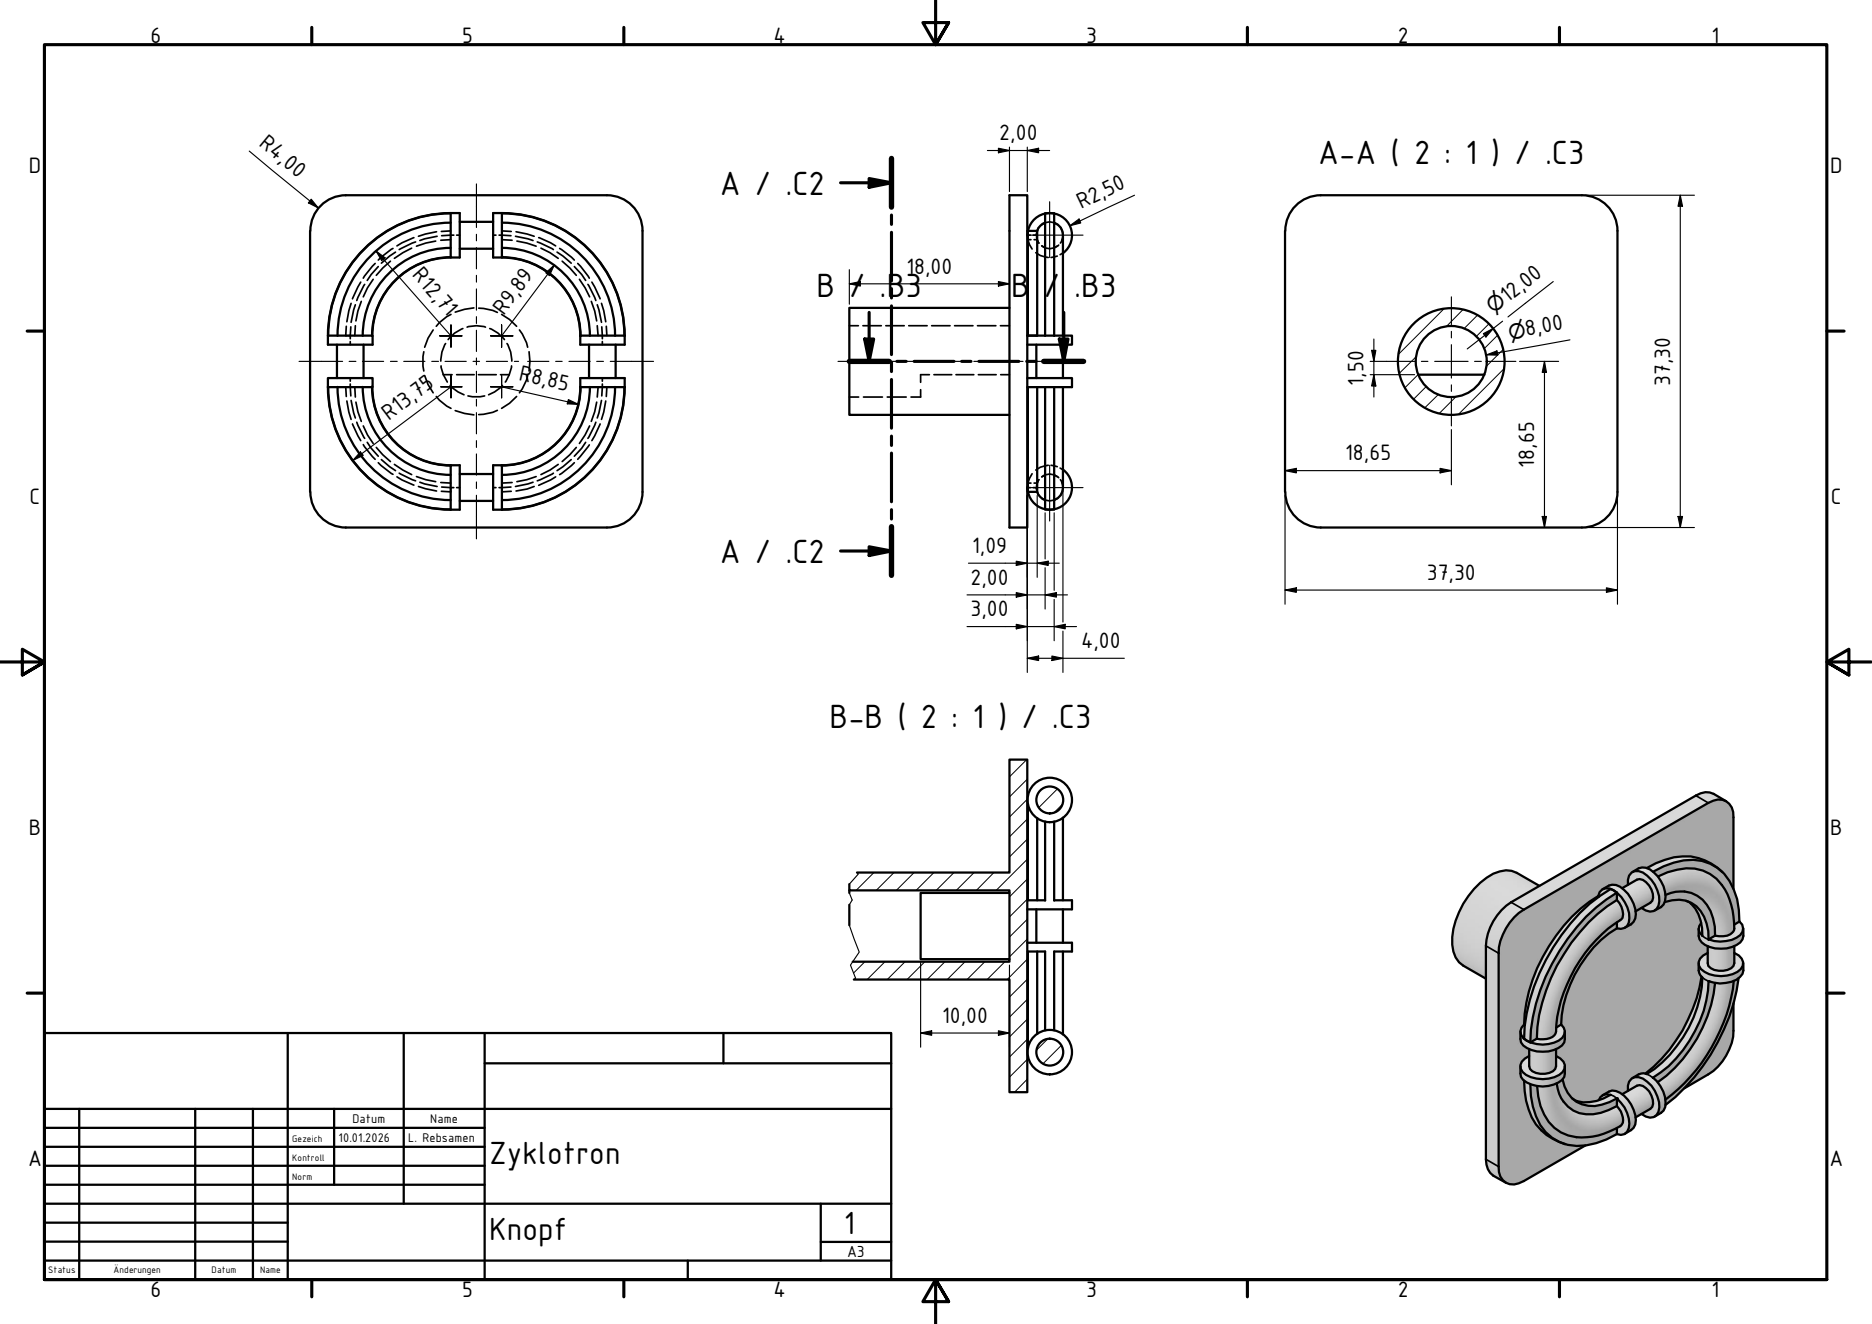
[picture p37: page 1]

Datum | Name | Zyklotron

Gezeich | 10.01.2026 | L. Rebsamen

Kontroll

Norm

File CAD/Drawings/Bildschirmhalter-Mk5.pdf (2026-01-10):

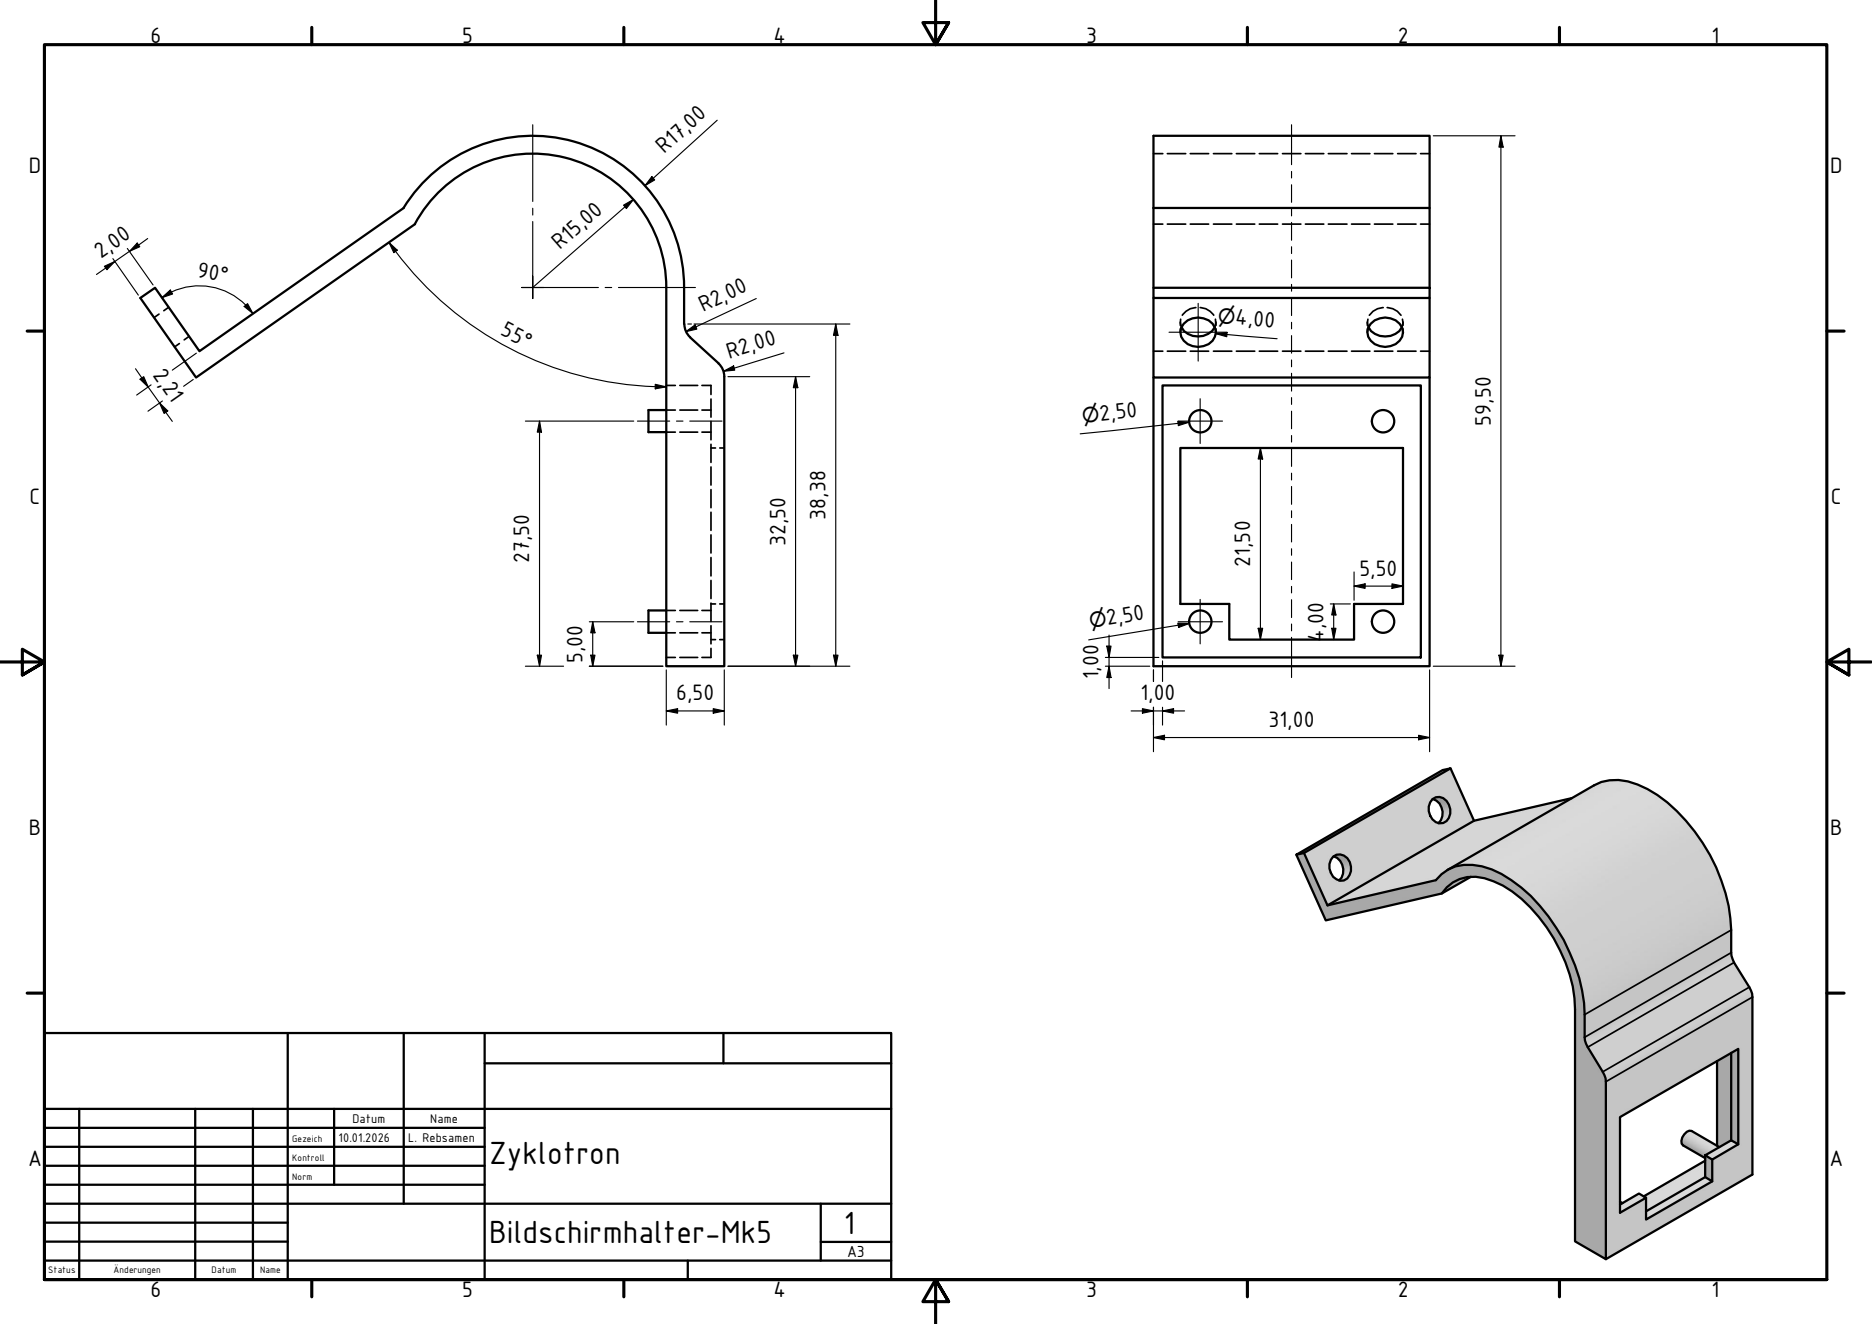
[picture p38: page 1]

G e z eic h | 1 0.0 1.2 0 2 6 | L. R e b s a m e n

Bil d s c hir m h a l t e r -M k 5 | 1A

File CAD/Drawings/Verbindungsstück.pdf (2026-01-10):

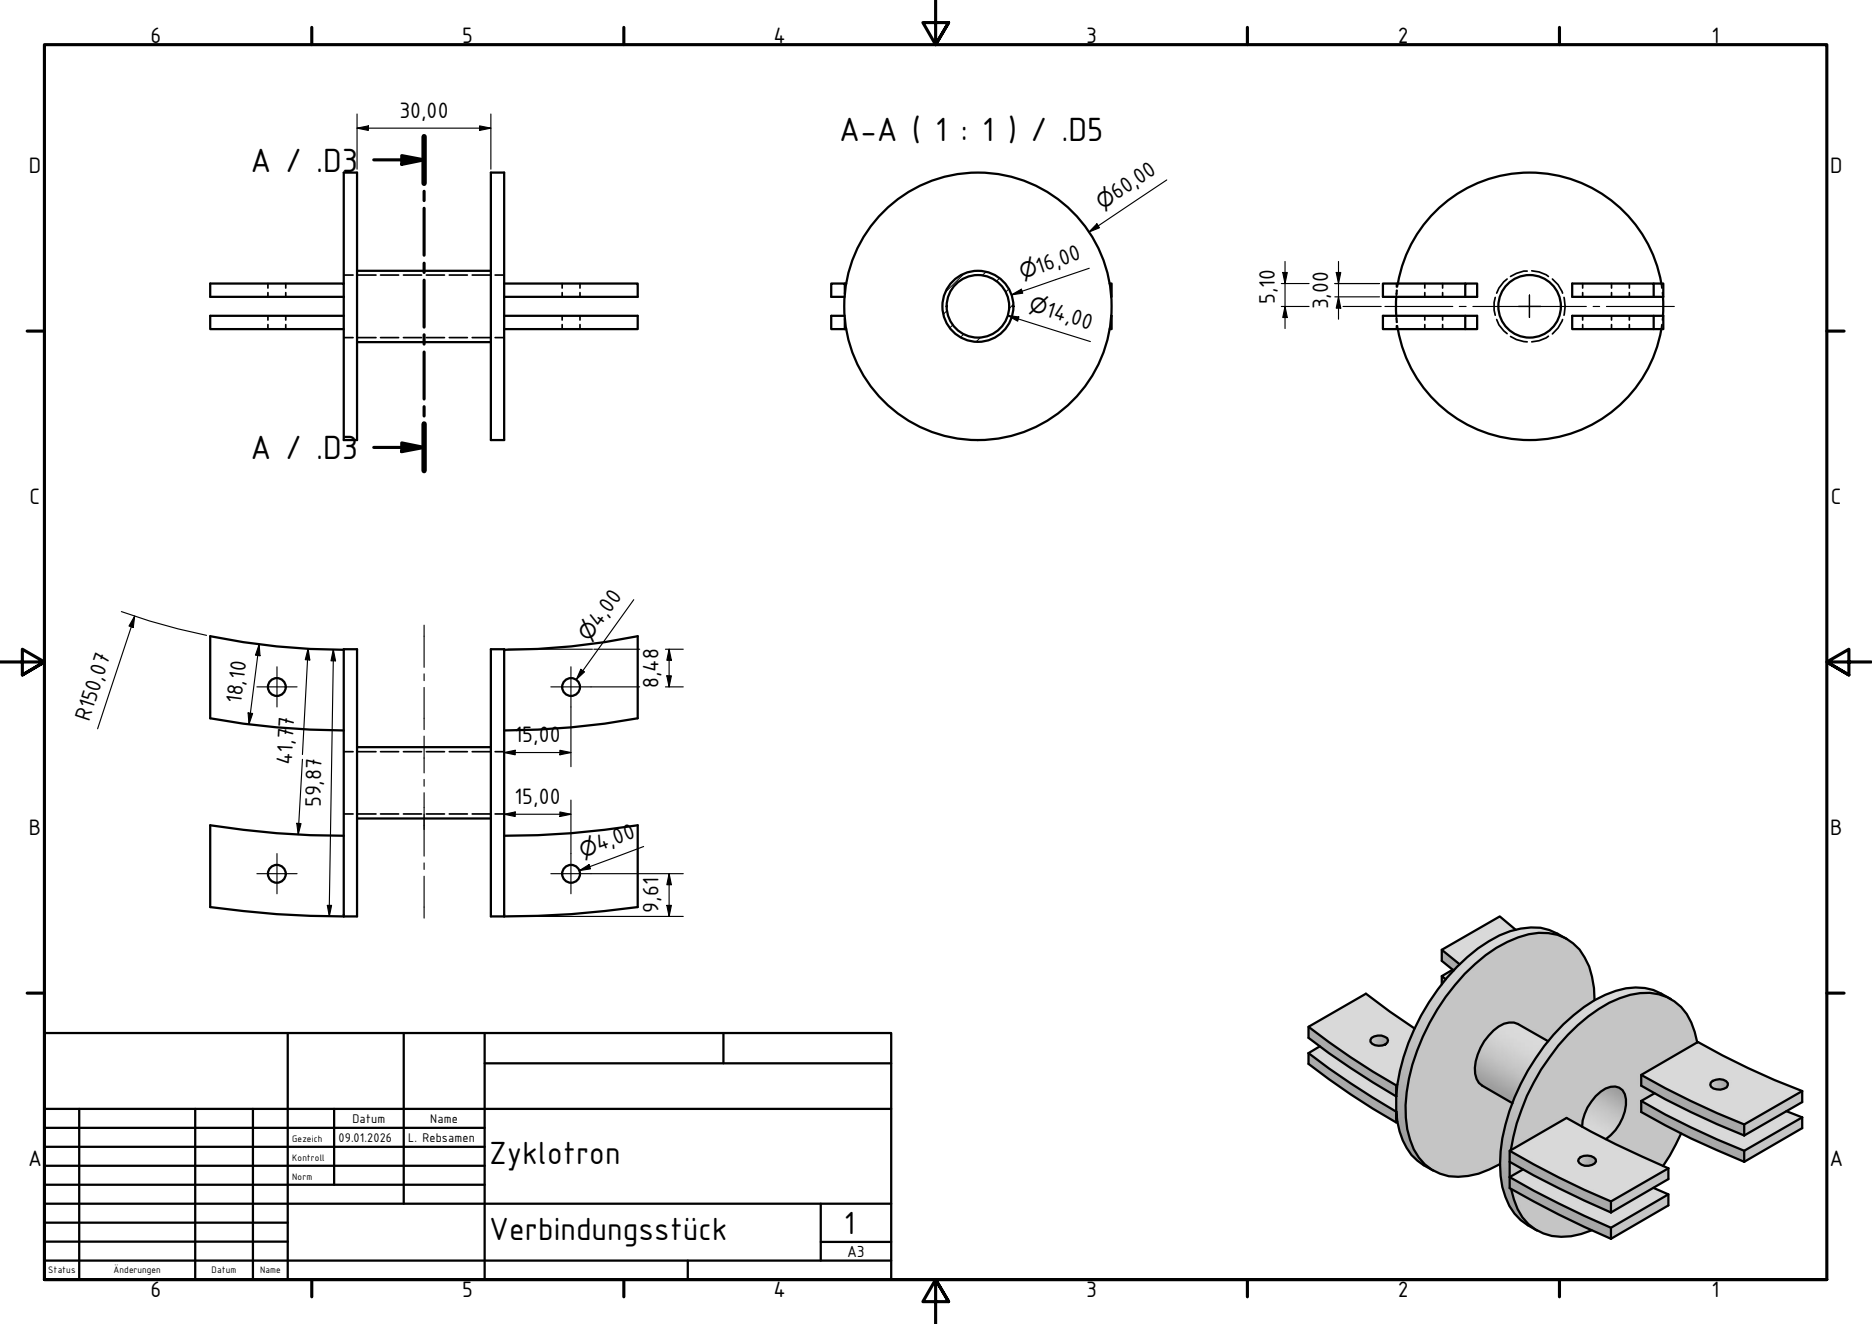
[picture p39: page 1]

G e z eic h | 0 9.0 1.2 0 2 6 | L. R e b s a m e n

V e r bin d u n g s s t ü c k | 1A

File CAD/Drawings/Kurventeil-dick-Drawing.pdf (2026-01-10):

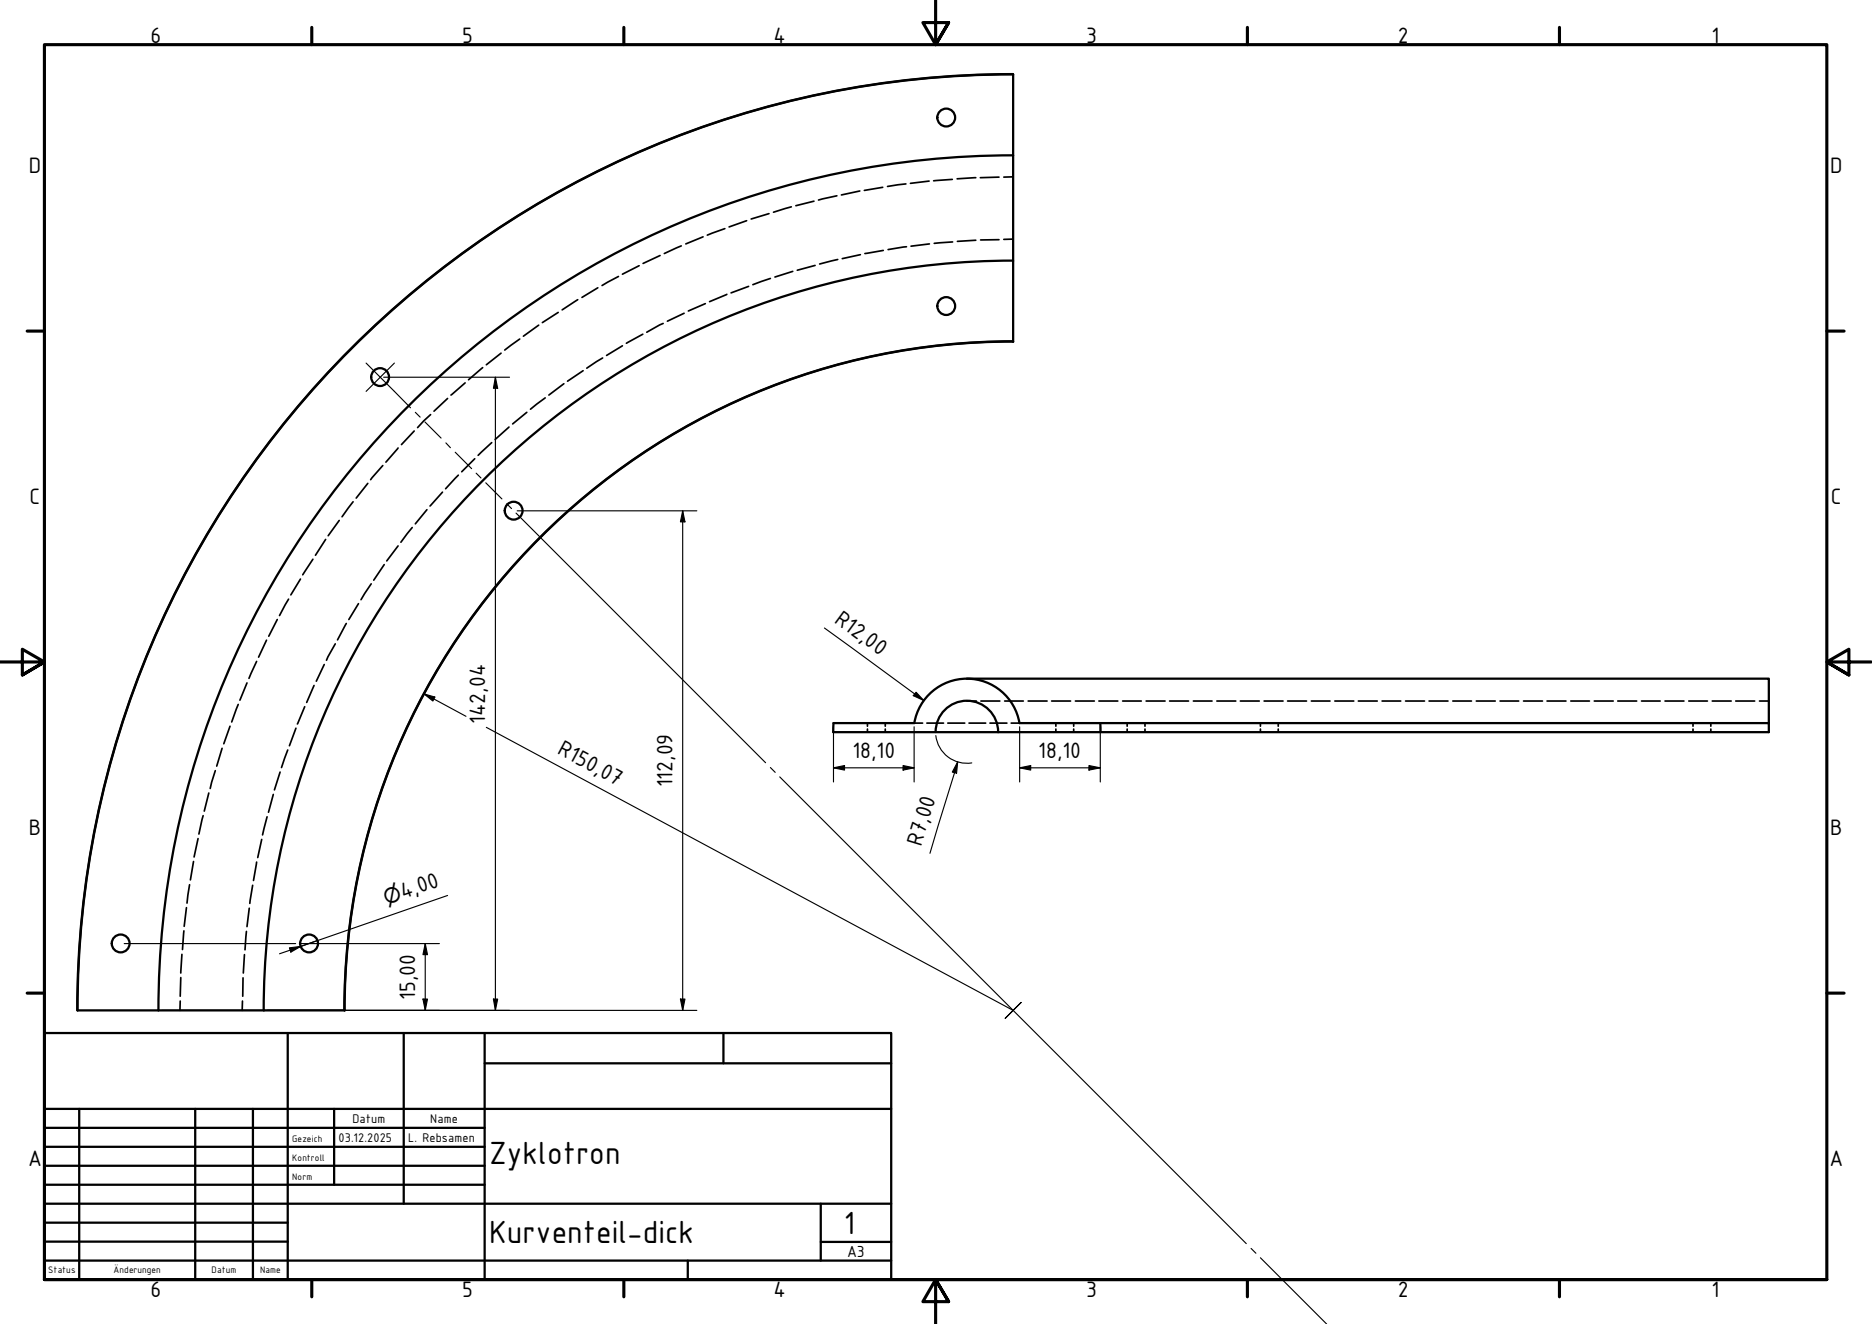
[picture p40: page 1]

G e z eic h | 0 3.1 2.2 0 2 5 | L. R e b s a m e n

K u r v e n t eil -dic k | 1A

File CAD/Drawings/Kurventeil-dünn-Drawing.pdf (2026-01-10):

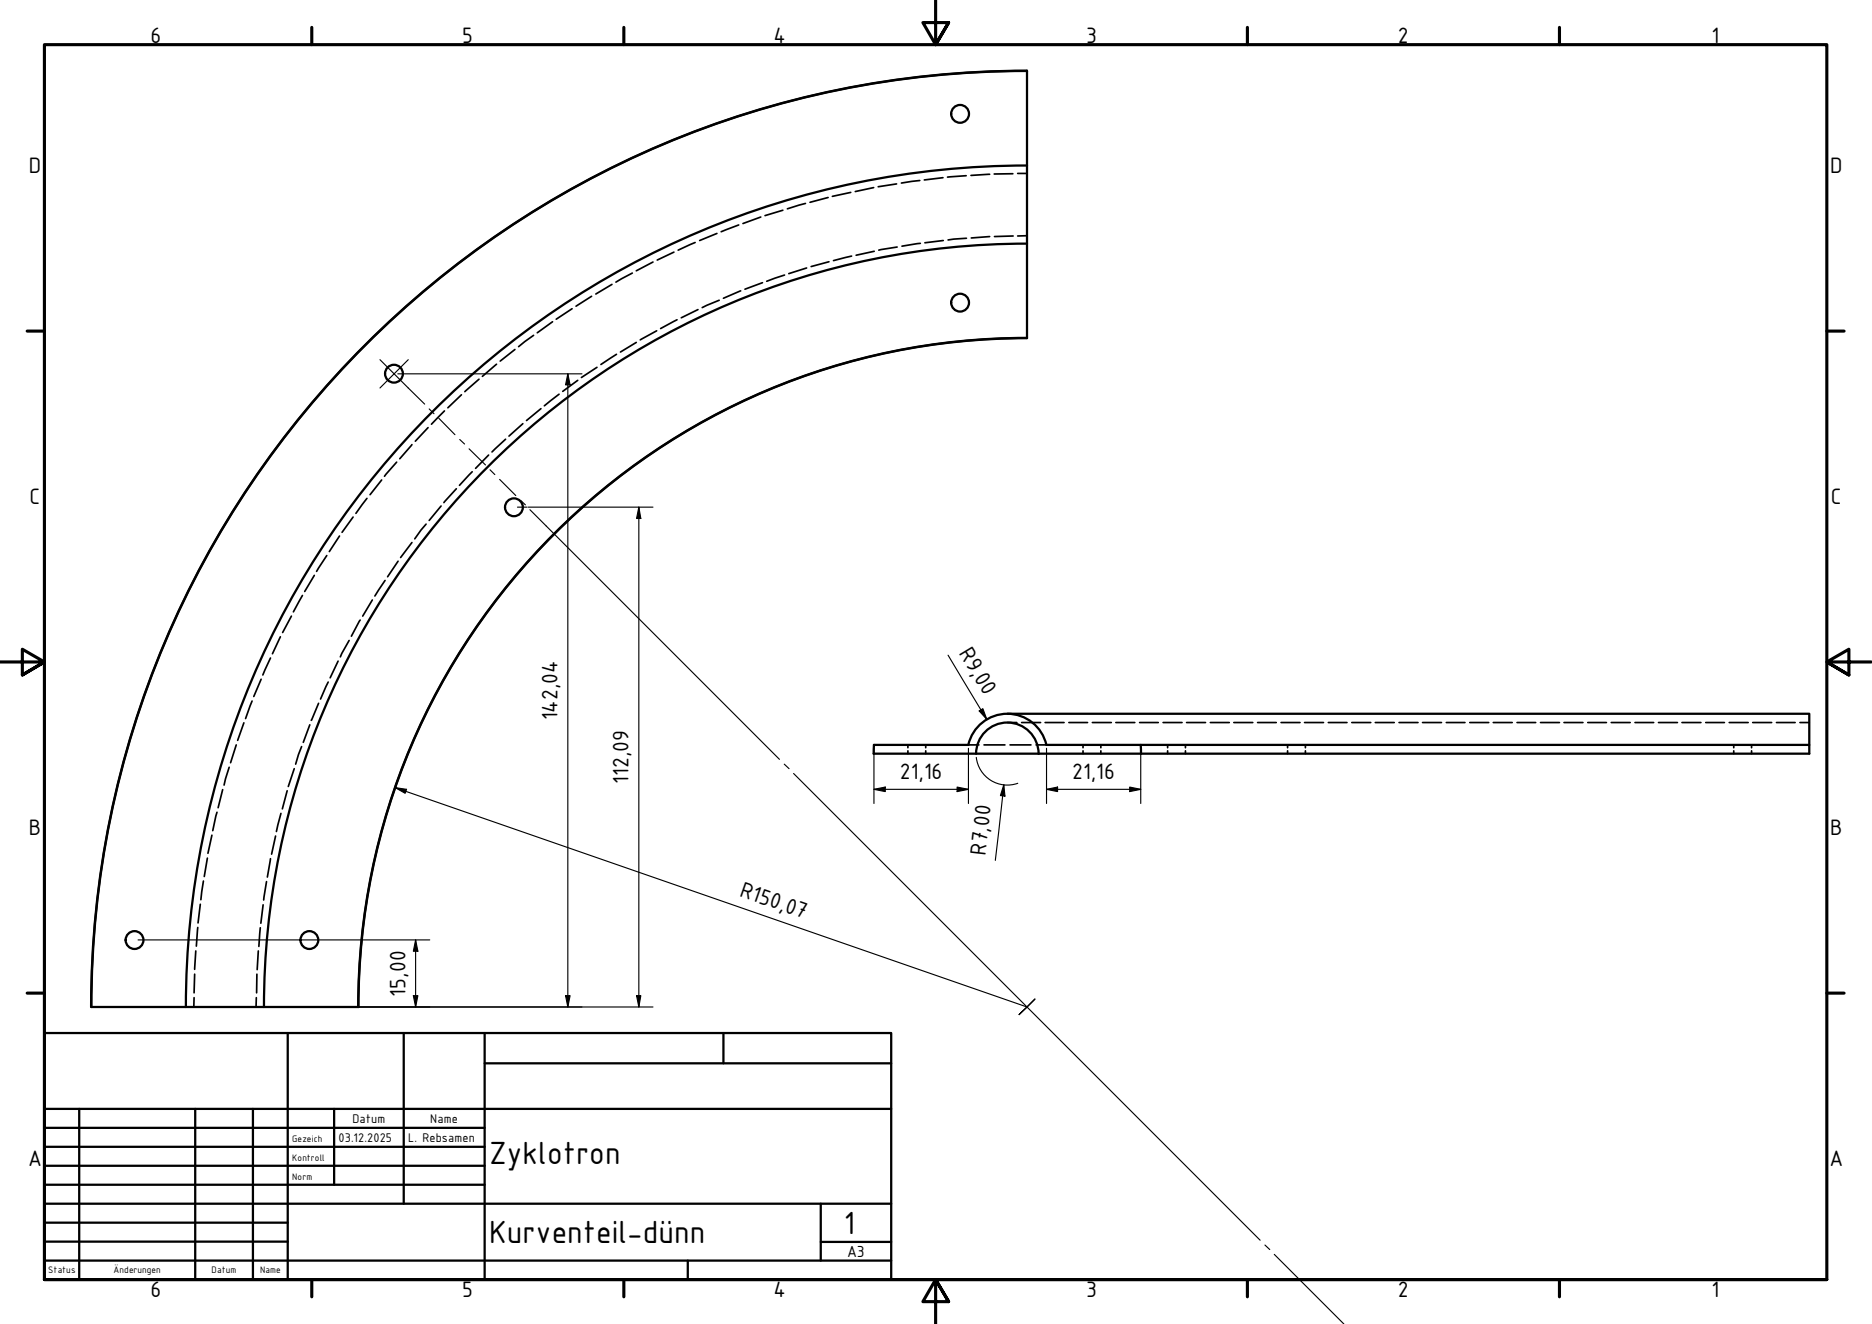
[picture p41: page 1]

Datum | Name | Zyklotron

Gezeich | 03.12.2025 | L. Rebsamen

Kontroll

Norm

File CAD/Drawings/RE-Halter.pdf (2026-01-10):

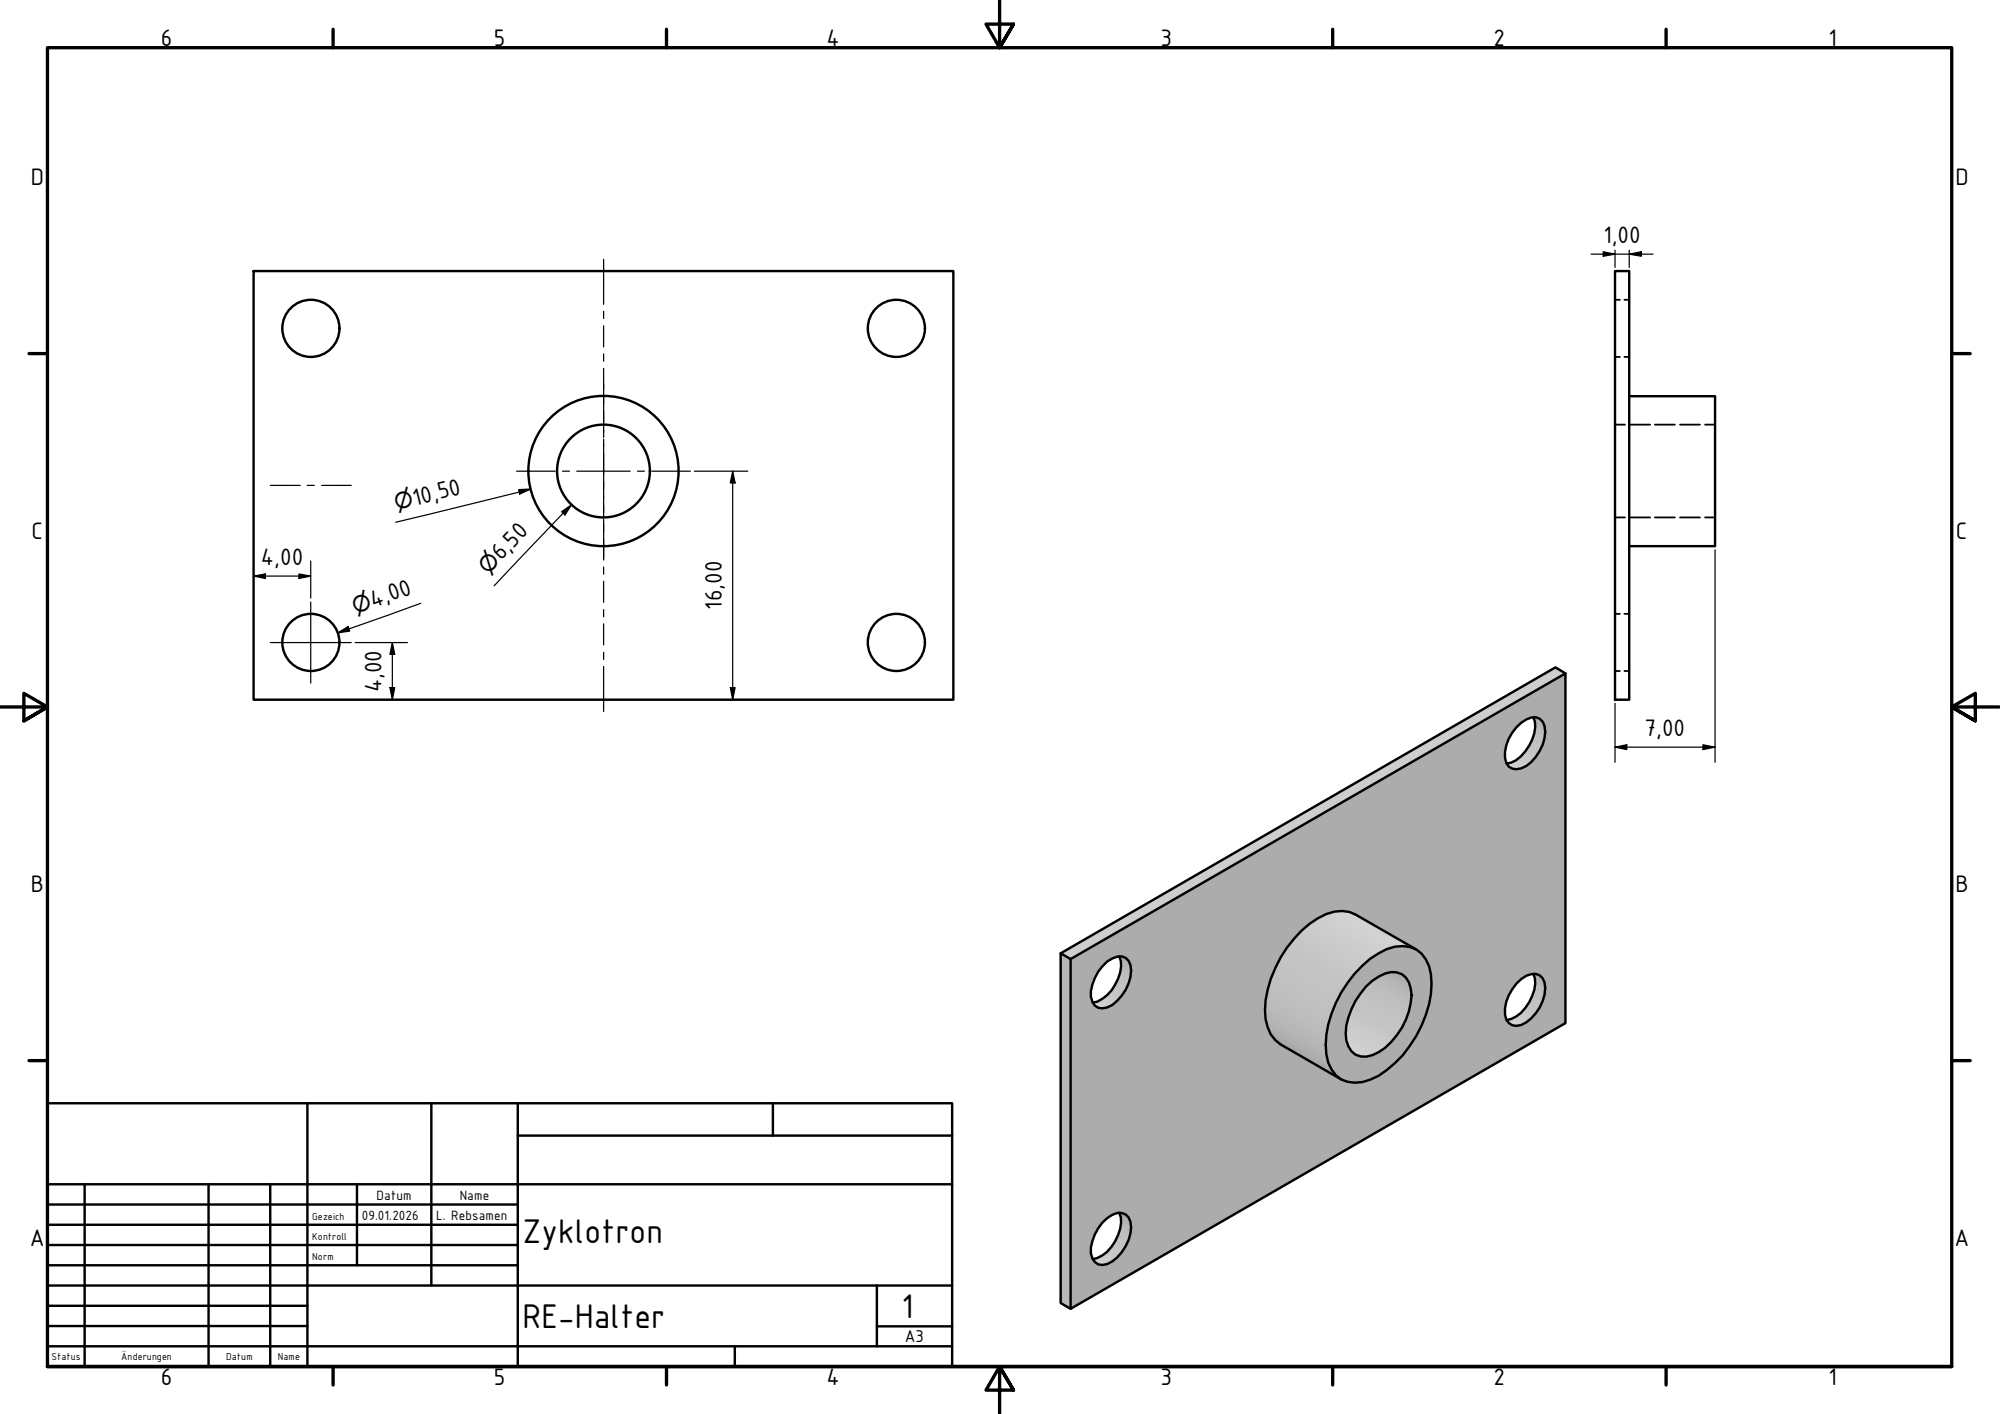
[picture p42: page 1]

Datum | Name | Zyklotron

Gezeich | 09.01.2026 | L. Rebsamen

Kontroll

Norm

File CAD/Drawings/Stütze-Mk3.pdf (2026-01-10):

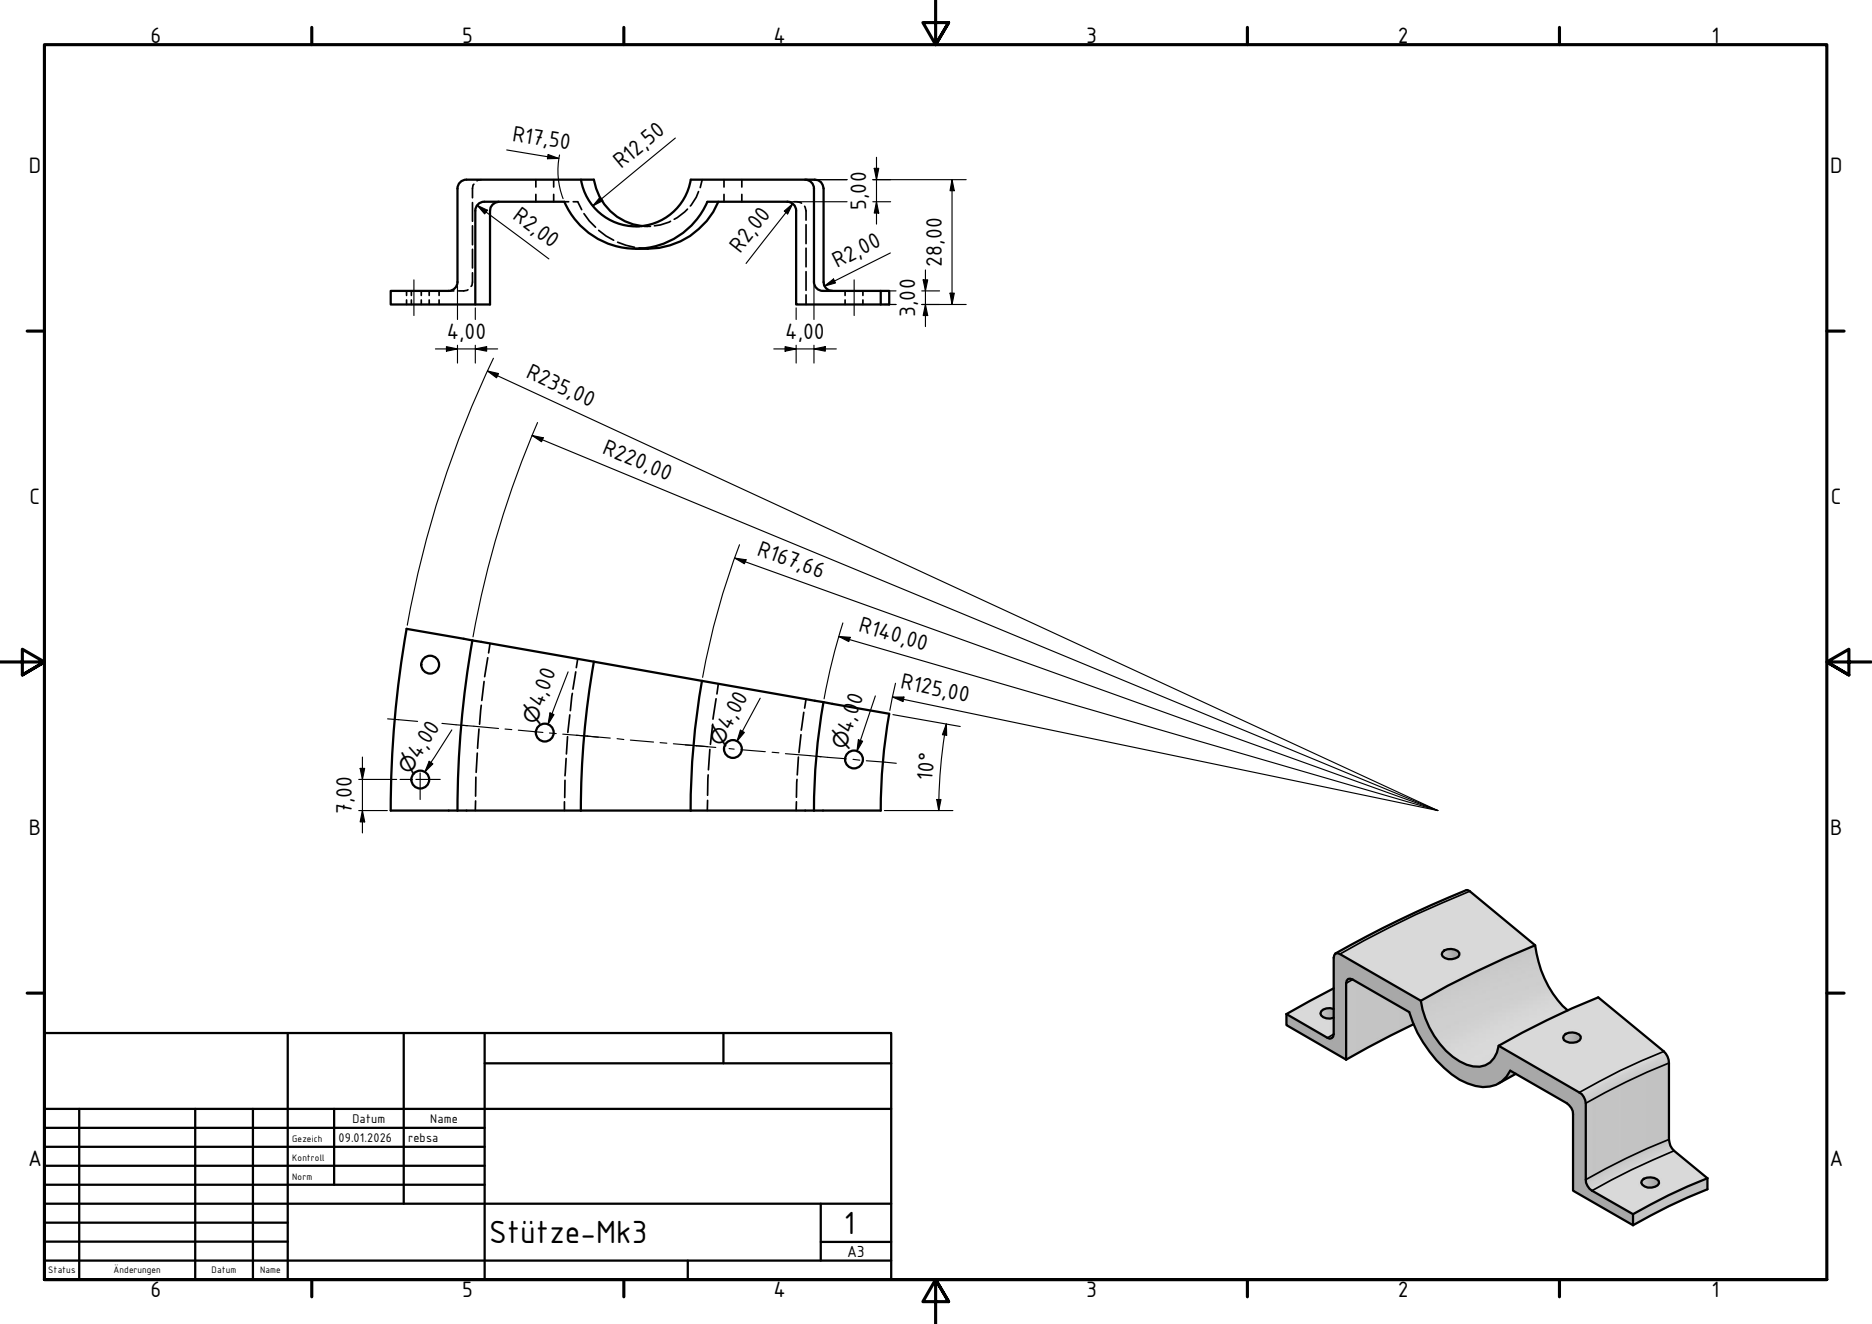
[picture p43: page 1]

G e z eic h | 0 9.0 1.2 0 2 6 | r e b s a

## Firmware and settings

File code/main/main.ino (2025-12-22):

#include <Arduino.h>
#include "globals.h"

void displayTask(void *pvParameters);
void relaisTask(void *pvParameters);

void setup() {
  Serial.begin(115200);

  tempoMutex = xSemaphoreCreateMutex();

  xTaskCreatePinnedToCore(
    displayTask,
    "DisplayTask",
    10000,
    NULL,
    2,
    NULL,
    1        // Core 1 → UI
  );

  xTaskCreatePinnedToCore(
    relaisTask,
    "RelaisTask",
    4096,
    NULL,
    1,
    NULL,
    0        // Core 0 → Logik
  );
}

void loop() {
  vTaskDelay(portMAX_DELAY);
}

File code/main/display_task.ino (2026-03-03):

#include <Arduino.h>
#include <Wire.h>
#include <Adafruit_GFX.h>
#include <Adafruit_SSD1306.h>
#include <ESP32Encoder.h>

#include "globals.h"

// ---------- OLED ----------
#define SCREEN_WIDTH 128
#define SCREEN_HEIGHT 64
#define OLED_RESET -1
#define OLED_ADDRESS 0x3C

#define SDA_PIN 22  // OLED SDA
#define SCL_PIN 23  // OLED SCK / SCL

Adafruit_SSD1306 display(SCREEN_WIDTH, SCREEN_HEIGHT, &Wire, OLED_RESET);

// ---------- PINBELEGUNG ----------
const int CLK = 27;
const int DT = 14;
const int SW = 26;

const int redPin = 21;
const int greenPin = 19;
const int bluePin = 18;

int redValue = 75;
int blueValue = 75;
int greenValue = 75;

// ---------- ENCODER ----------
ESP32Encoder encoder;

// ---------- EINSTELLUNGEN ----------
const int minWert = 0;
const int maxWert = 100;

// ---------- LAYOUT-TYPEN ----------
enum SeitenLayout {
  LAYOUT_BALKEN,
  LAYOUT_GROSSZAHL,
  LAYOUT_TEXT
};

// ---------- SEITENSTRUKTUR ----------
struct Seite {
  const char *titel;
  SeitenLayout layout;
  int wert;
};

// ---------- SEITEN DEFINIEREN ----------
Seite seiten[] = {
  { "Helligkeit Rot", LAYOUT_BALKEN, 75 },
  { "Helligkeit Blau", LAYOUT_BALKEN, 75 },
  { "Helligkeit Grün", LAYOUT_BALKEN, 75 },
  { "Tempo", LAYOUT_GROSSZAHL, 100 },
  { "Status", LAYOUT_TEXT, 0 }
};

const int anzahlSeiten = sizeof(seiten) / sizeof(seiten[0]);

// ---------- VARIABLEN ----------
int aktuelleSeite = 0;
long letzteEncoderPos = 0;

bool editModus = false;
bool letzterButtonStatus = HIGH;
unsigned long letzteButtonZeit = 0;
const unsigned long entprellZeit = 200;

// ---------- FUNKTIONSDEKLARATIONEN ----------
void zeichneAktuelleSeite();
void zeichneBalkenSeite(Seite &s);
void zeichneGrosszahlSeite(Seite &s);
void zeichneTextSeite(Seite &s);

// ======================================================
// ================== DISPLAY TASK ======================
// ======================================================

void displayTask(void *pvParameters) {

  // ---------- INITIALISIERUNG ----------
  Wire.begin(SDA_PIN, SCL_PIN);
  display.begin(SSD1306_SWITCHCAPVCC, OLED_ADDRESS);
  display.clearDisplay();

  display.setTextColor(SSD1306_WHITE);
  display.setTextSize(2);

  pinMode(SW, INPUT_PULLUP);
  pinMode(redPin, OUTPUT);
  pinMode(greenPin, OUTPUT);
  pinMode(bluePin, OUTPUT);

  digitalWrite(redPin, HIGH);
  digitalWrite(greenPin, HIGH);
  digitalWrite(bluePin, HIGH);

  ESP32Encoder::useInternalWeakPullResistors = puType::up;
  encoder.attachHalfQuad(DT, CLK);
  encoder.clearCount();

  zeichneAktuelleSeite();

  // ---------- TASK LOOP ----------
  while (true) {

    // ----- BUTTON -----
    bool button = digitalRead(SW);
    if (button == LOW && letzterButtonStatus == HIGH) {
      if (millis() - letzteButtonZeit > entprellZeit) {
        editModus = !editModus;
        letzteButtonZeit = millis();
        zeichneAktuelleSeite();
      }
    }
    letzterButtonStatus = button;

    // ----- ENCODER -----
    long pos = encoder.getCount() / 2;
    if (pos != letzteEncoderPos) {
      int richtung = (pos > letzteEncoderPos) ? 1 : -1;

      if (!editModus) {
        aktuelleSeite += richtung;
        if (aktuelleSeite >= anzahlSeiten) aktuelleSeite = 0;
        if (aktuelleSeite < 0) aktuelleSeite = anzahlSeiten - 1;
      } else {
        seiten[aktuelleSeite].wert += richtung;
        if (seiten[aktuelleSeite].wert > maxWert) seiten[aktuelleSeite].wert = maxWert;
        if (seiten[aktuelleSeite].wert < minWert) seiten[aktuelleSeite].wert = minWert;

        // ----- TEMPO THREADSICHER ÜBERNEHMEN -----
        if (strcmp(seiten[aktuelleSeite].titel, "Tempo") == 0) {
          xSemaphoreTake(tempoMutex, portMAX_DELAY);
          tempoWert = seiten[aktuelleSeite].wert;
          xSemaphoreGive(tempoMutex);
        }

        if (strcmp(seiten[aktuelleSeite].titel, "Helligkeit Rot") == 0) {
          redValue = seiten[aktuelleSeite].wert;
        }

        if (strcmp(seiten[aktuelleSeite].titel, "Helligkeit Blau") == 0) {
          blueValue = seiten[aktuelleSeite].wert;
        }

        if (strcmp(seiten[aktuelleSeite].titel, "Helligkeit Grün") == 0) {
          greenValue = seiten[aktuelleSeite].wert;
        }
      }

      letzteEncoderPos = pos;
      zeichneAktuelleSeite();
    }

    vTaskDelay(10 / portTICK_PERIOD_MS);
  }

  analogWrite(redPin, 255 - map(redValue, 0, 100, 0, 255));
  analogWrite(greenPin, 255 - map(greenValue, 0, 100, 0, 255));
  analogWrite(bluePin, 255 - map(blueValue, 0, 100, 0, 255));
}

// ======================================================
// ================== ZEICHENFUNKTIONEN =================
// ======================================================

void zeichneAktuelleSeite() {
  Serial.println(seiten[aktuelleSeite].titel);
  display.clearDisplay();

  // Überschrift
  display.setTextSize(1);
  display.setTextColor(SSD1306_WHITE);
  display.setCursor(0, 0);
  display.println(seiten[aktuelleSeite].titel);
  display.drawLine(0, 10, 127, 10, SSD1306_WHITE);

  switch (seiten[aktuelleSeite].layout) {
    case LAYOUT_BALKEN:
      zeichneBalkenSeite(seiten[aktuelleSeite]);
      break;

    case LAYOUT_GROSSZAHL:
      zeichneGrosszahlSeite(seiten[aktuelleSeite]);
      break;

    case LAYOUT_TEXT:
      zeichneTextSeite(seiten[aktuelleSeite]);
      break;
  }

  display.display();
}

void zeichneBalkenSeite(Seite &s) {
  display.setCursor(0, 20);
  display.print("Wert: ");
  display.print(s.wert);
  display.print("%");

  Serial.print("Wert: ");
  Serial.print(s.wert);
  Serial.println("%");

  display.drawRect(0, 35, 128, 10, SSD1306_WHITE);
  int breite = map(s.wert, 0, 100, 0, 126);
  display.fillRect(1, 36, breite, 8, SSD1306_WHITE);
}

void zeichneGrosszahlSeite(Seite &s) {
  display.setTextSize(3);
  display.setCursor(10, 25);
  display.print(s.wert);
  display.setTextSize(1);
}

void zeichneTextSeite(Seite &s) {
  display.setCursor(0, 20);
  display.println("System OK");
  display.println("Keine Fehler");
}
